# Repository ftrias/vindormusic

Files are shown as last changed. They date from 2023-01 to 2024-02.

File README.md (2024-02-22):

Vindor ES Source Code
=====================

This repository holds the source code, modules and PCB layouts of the Vindor ES1/2 electronic saxophone and wind instrument (clarinet, flute, trumpet, etc.). More information is available at [Vindor Music](http://vindormusic.com)

Directories
-----------

| Directory | Contents
| --- | ---
| /apps | Mobile and web apps
| /apps/juce-gui | Main control app for Mac/Win/iOS/Android
| /apps/splayer | Free generic MIDI player
| /firmware | Source for firmware and related modules
| /firmware/source | ES1/2 main source
| /firmware/external  | Non-Vindor open source libraries used
| /pcb | KiCad source for PCB
| /shell | Solidworks models for the shell
| /documents | Documentation and promotional material
| /sounds | Sound files for use on SD cards

License
-------

Unless otherwise noted, the software is Copyright (c) 2023 by Fernando Trias and Vindor Music, Inc. The software is licensed for use under the Creative Commons license available in `LICENSE.txt` and summarized on the [CC page](https://creativecommons.org/licenses/by-nc/3.0/).

This software uses external modules that are distributed according to their own licenses, which are all open source.

To summarize:
1. You may freely use this software for non-commercial purposes.
2. You must give appropriate credit to respective authors.

History
---------
This project began in 2016 to produce an affordable electronic wind instrument. At that time, the market was dominated by Yamaha and Akai. Both produced superb instruments that were prohibitively expensive for casual musicians. In addition, there were a number of small niche manufacturers targeting advanced players. Although Akai produced a low-cost USB instrument, it was large, heavy and had limited market penetration. In addition, we wanted to create an easy-to-use low-cost alternative for beginning players that would be both stand-alone and interface easily with Garageband and similar apps popular with younger musicians.

The Vindor began with a Kickstarter campaign and started being sold commercially in 2018 both online and in stores. It was covered by numerous blogs and journals, including Fast Company and the Boston Globe. In 2019, Roland release the Aerophone Mini AE-01, which although larger and slightly more expensive than the Vindor, targeted the same entry-level market. This, combined with the COVID shutdown and subsequent rise in component costs, made producing more Vindors impractical and all existing inventory was sold out by late 2020. 

By 2023, the chip market had not recovered and it still not possible to make more Vindors (the main CPU is still unavailable). Since Vindor Music closed its doors, we have decided to open source the firmware and apps, as well as the PCB, BOM and other components.

Open Source Announcement
------------------------

Vindor Music has open sourced the ES1 electronic wind instrument software and hardware. The Vindor ES1 was a low-cost entry-level electronic wind instrument that launched in 2018 and sold until 2020, a casualty of the COVID pandemic. The release includes all the source for the firmware, Android, iOS, Mac and Windows apps, as well as the BOM, schematics and PCB layout of the circuit boards. It includes everything you need to make your own ES1 and program it to do whatever you like. We hope this will inspire hobbyists to port the ES1 to a new CPU and continue the mission of providing an affordable and functional electronic wind instrument. The source can be found at https://github.com/ftrias/vindormusic.

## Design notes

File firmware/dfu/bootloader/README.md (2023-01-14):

Fadecandy Bootloader
====================

This is a simple open source bootloader for the Freescale Kinetis MK20DX128 microcontroller. It uses the USB Device Firmware Upgrade (DFU) standard. This bootloader was developed for use with Fadecandy, but it should be portable with to other projects using chips in the Kinetis microcontroller family.

Installing
----------

On a Teensy 3.0, you can use the Teensy Loader application to install `fc-boot.hex`. Afterwards, your Teensy should appear to the system as a "Fadecandy Bootloader" USB device capable of loading an application firmware image.

On a Fadecandy fc64x8 board, the bootloader can be installed via JTAG using OpenOCD. If you have an Olimex ARM-USB-OCD adapter, everything's already set up to install the bootloader with "make install". Other JTAG adapters will require changing `openocd.cfg`.

Application Interface
---------------------

This section describes the programming interface that exists between the bootloader and the application firmware.

The bootloader uses the smallest possible protected region on the MK20DX128's flash, a 4KB block. It uses a tiny amount of RAM for a "token" which is used to force entry into the bootloader on system reset.

When entering the application firmware, the system clocks will already be configured, and the watchdog timer is already enabled with a 10ms timeout. The application may disable the watchdog timer if desired.

The bootloader normally transfers control to the application early in boot, before setting up the USB controller. It will skip this step and run the DFU implementation if any of the following conditions are true:

* A banner ("FC-Boot\n") printed to the hardware UART at 9600 baud is echoed back within one character-period. (Manual entry by shorting TX and RX)
* A 32-bit entry token (0x74624346, or 'FCbt') is found at 0x2000_1FFC. (Programmatic entry)
* The application ResetVector does not reside within application flash. (No application is installed)

Memory address range       | Description
-------------------------- | ----------------------------
0x0000_0000 - 0x0000_0FFF  | Bootloader protected flash
0x0000_1000 - 0x0000_10F7  | Application IVT in flash
0x0000_1000 - 0x0001_FFFF  | Remainder of application flash
0x1FFF_E000 - 0x2000_1FFC  | Application SRAM
0x2000_1FFC - 0x2000_1FFF  | Entry token in SRAM

External Hardware
-----------------

No external hardware is required for the bootloader to operate. The following pins are used by the bootloader for optional features:

* PC5 is a status LED, active (high) while the bootloader is in DFU mode.
* PCR16/17 are set up as UART0 briefly during boot, for broadcasting the banner message and testing for manual bootloader entry.

File Format
-----------

The DFU file consists of raw 1 kilobyte blocks to be programmed into flash starting at address 0x0000_1000. The file may contain up to 127 blocks. No additional headers or checksums are included. On disk, the standard DFU suffix and CRC are used. During transit, the standard USB CRC is used.

Contact
-------

Micah Elizabeth Scott <<micah@scanlime.org>>

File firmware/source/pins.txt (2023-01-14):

 Notes on pin connections: R45

 Pin = K20 pin designation
 ##  = Teensy emulation pin number
 Purpose = Notes on use

 Pin   ## Purpose
 ----- -- -------------
 PTA0     SWD Clock
 PTA1  34X T9 CH2
 R44< PTA2  #? SET
 R45> PTA2  35X Tb CH3
 PTA2  #? SET
 PTA3     SWD DIO
 PTA4  33 T6 CH5
 R44< PTA5  24 SD card det
 R45> PTA5  24 SET
 PTA12  3 SG I2S DIN (I2S0_TXD0)
 PTA13  4 SG I2S LRCLK
 PTA18  X Clock
 PTA19  X Clock
 PTB0  16 T4 CH0
 PTB1  17 T5 CH6
 PTB2  19 T8 CH7
 PTB3  18 T7 CH8
 PTB16  0 T1 CH9
 PTB17  1 T2 CH10
 PTB18 32 T3 CH11
 PTB19 25 T11 CH12
 PTC0  15 T10 CH13
 PTC1  22 T_HI CH14
 PTC2  23 T_LO CH15
 PTC3   9 SG I2S_SCLK
 PTC4  10 SD CD/DAT3
 PTC5  13 SD CLK (SCK)
 PTC6  11 SD CMD (DOUT MOSI)
 PTC7  12 SD DAT0 (DIN MISO)
 PTC8  28 SG MCLK
 PTC9  27 LDO EN
 PTC10 29 SG CTRL_CLK
 PTC11 30 SG CTRL_DATA
 PTD0   2 AMP SHDN
 X18  A14 Air Pressure (K20 pin ADC_SE23)
 PTD2   7 Serial3 RX
 PTD3   8 Serial3 TX
 PTD4   6 LED Red
 PTD5  20 SG I2S DOUT? - should connect to I2S0_RXD0
 PTD6  21 LED Green
 PTD7   5 LED Blue
 PTE0  31 HP Jack Det
 PTE1  26 Line Jack Det
 PTE4  38 Accelerometer CS
 PTE5  39 Accelerometer control button

 Free pin #14 PTD1
 Possible changes to free more digital pins: move HP/Line jack detect to ADC_DP* and remove interrupt on those lines

 Revision R53 w/ 64-pin chip
 PTE0      31 Accel CS
 PTE1      26 Accel button
 ADC0_DM0 A11 Battery volt
 ADC0_DP0 A10 HP_JACK HP Jack Det
 PTD1      14 Line Jack Det

 Why is VREF_OUT connected to ground via capacitor? High pass filter?

Notes on pin connections: R57

 Pin = K20 pin designation
 ##  = Teensy emulation pin number
 Purpose = Notes on use

 Pin   ##   Purpose
 ----- --   -------------
 PTA0       SWDCLK SWD Clock
 PTA1  34X  T8 CH2
 PTA2  35X  Tb CH3
 PTA3       SWDIO SWD DIO
 PTA4  33   T5 CH5
 PTA5  24   SET button
 PTA12  3   SGTL5000 I2S DIN (I2S0_TXD0)
 PTA13  4   SGTL5000 I2S LRCLK
 PTA18  X   Clock
 PTA19  X   Clock
 PTB0  16   T3 CH0
 PTB1  17   T4 CH6
 PTB2  19   T7 CH7
 PTB3  18   T6 CH8
 PTB16  0   T11 CH9
 PTB17  1   T1 CH10
 PTB18 32   T2 CH11
 PTB19 25   T10 CH12
 PTC0  15   T9 CH13
 PTC1  22   T_HI CH14
 PTC2  23   T_LO CH15
 PTC3   9   SGTL5000 I2S_SCLK
 PTC4  10   SD CD/DAT3
 PTC5  13   SD CLK (SCK) / Accl SCL
 PTC6  11   SD CMD (DOUT MOSI) / Accel SDA
 PTC7  12   SD DAT0 (DIN MISO) / Accel SDO
 PTC8  28   SGTL5000 MCLK
 PTC9  27   AUDIO SPEAKER LDO EN
 PTC10 29   SGTL5000 CTRL_CLK / Var Pot SCL / Display
 PTC11 30   SGTL5000 CTRL_DATA / Var Pot SDA / Display
 PTD0   2   AMP SPEAKER SHDN
 X18  A14   Air Pressure (K20 pin ADC_SE23)
 PTD1  14   Amplifier Lineout Jack
 PTD2   7   Serial3 RX / JESP01:RX
 PTD3   8   Serial3 TX / JESP01/TX
 PTD4   6   LED Red
 PTD5  20   SGTL5000 I2S DOUT
 PTD6  21   LED Green
 PTD7   5   LED Blue
 PTE0  31   Accelerometer CS
 PTE1  26   Thumb switch
 ADC0_DM0 A11 Battery volt reading
 ADC0_DP0 A10 HP_JACK HP Jack Det
 ADC0_DM3     -Free
 ADC0_DP3     -Free

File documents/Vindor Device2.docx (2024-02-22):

# Vindor Assembly

# Overview

# Bottom

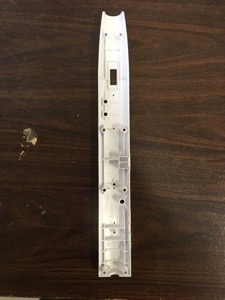
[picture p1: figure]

Place thick grounding wires into holes from the bottom. Long side of the wire goes toward the front.

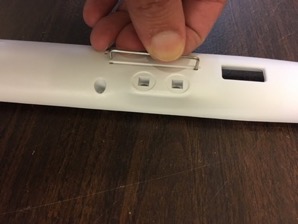
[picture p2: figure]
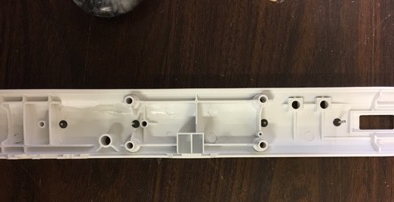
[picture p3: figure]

Find the small “Octave” PCB and attach LCD/OLED display.

Insert into bottom shell making sure that LCD fills hole completely.

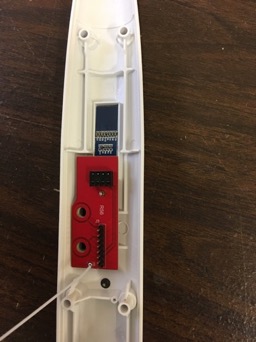
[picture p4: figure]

Attach cylinder on white wire to the thick grounding wire near the thumb hook.

Place the thumb hook and screw in with ½” screw.

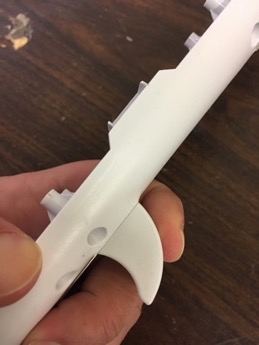
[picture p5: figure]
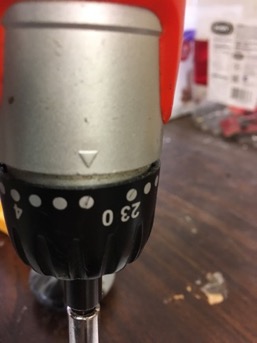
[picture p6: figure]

Attach tubes to the mouthpiece holder. Middle tube is smaller than outer tube. Then attach other end of the bigger tube to the hole near the far side of the bottom shell.

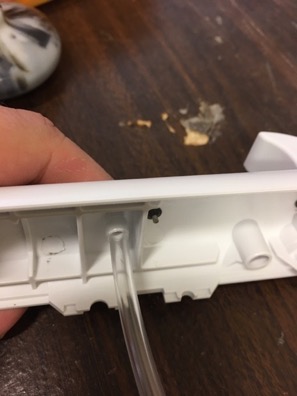
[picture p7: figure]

Place two carriage bolts. Then screw nuts from the opposite side using torque 4. Use locktite.

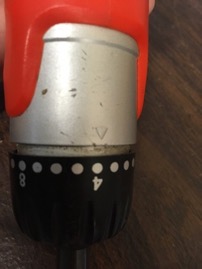
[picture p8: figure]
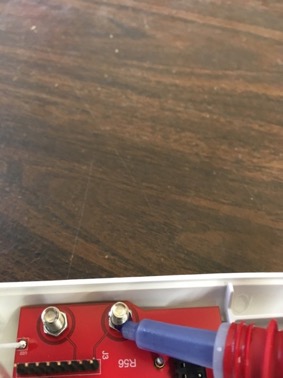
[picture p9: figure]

Use hot glue to permanently attach LCD/OLED to the shell. This prevents users from pushing the LCD into the shell.

# PCB prep

Place battery into PCB with plus side forward (see silkscreen on PCB) and ensure power switch is on by flipping it in the direction of the battery.

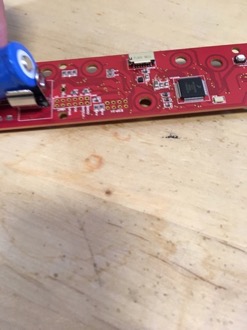
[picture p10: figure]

Flash the firmware. I use Segger J-Link.

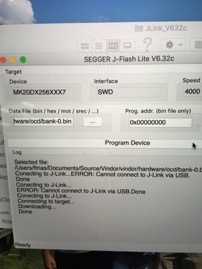
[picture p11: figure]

On the bottom side of the PCB, insert the button cap.

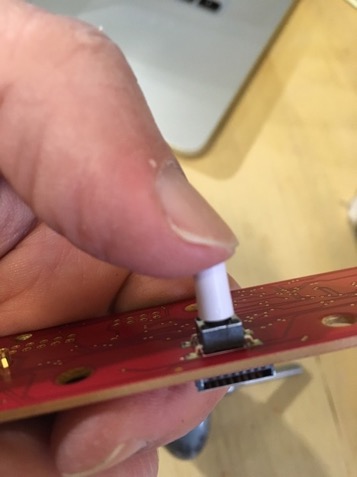
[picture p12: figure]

Near the battery, insert the light pipe. Then place the switch cap on the power switch.

# Top

Place the speaker foam near the top. Make sure it is oriented correctly. Place the speaker and screw in ¼” screws (4 of them) using torque 0.

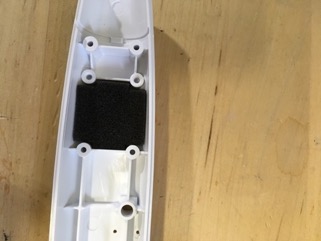
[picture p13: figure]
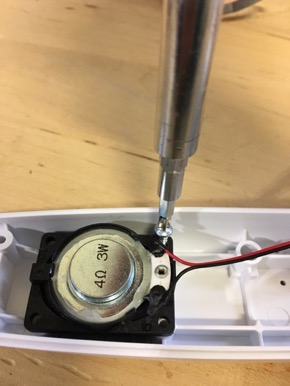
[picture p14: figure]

Optional. Place plastic washer on 4th hole and put in carriage screw.

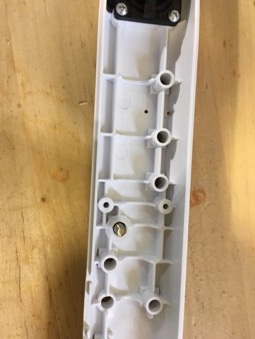
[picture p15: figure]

Attach bent wire into holes between first two bolt holes. Longer side goes on the inside, and shorter side on the outside. Use pressing tool to attach compression nut to the longer side of shell.

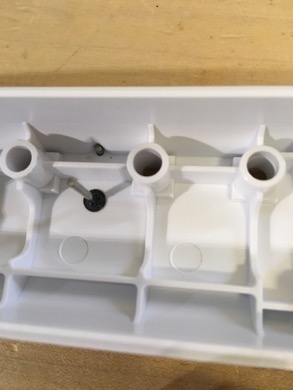
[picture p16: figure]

# Put it all together

Place the PCB into the top shell making sure the bent wire goes into the cylinder compression piece.

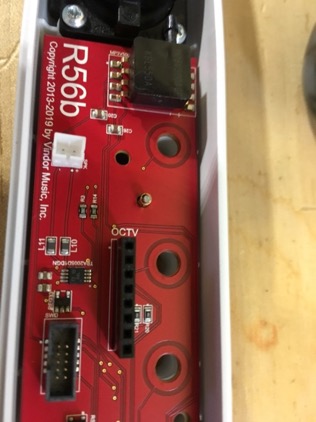
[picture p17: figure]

Optional. Screw in any bolts you optionally placed for support.

Carefully flip the top shell over and place all the carriage bolts into the proper holes.

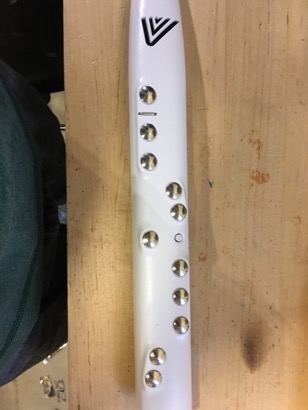
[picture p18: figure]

Place a piece of cardboard or other hard part on top of the shell and flip it over. The cardboard prevents the bolts from falling off.

Using a placement tool, put on all the nuts on the bolts.

Using torque 4, screw down the nuts.

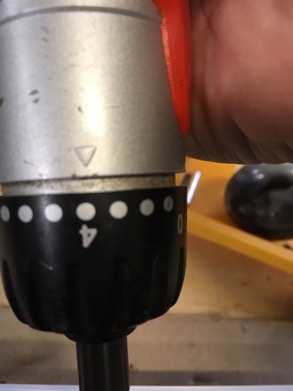
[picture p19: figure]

Use loctite on nuts.

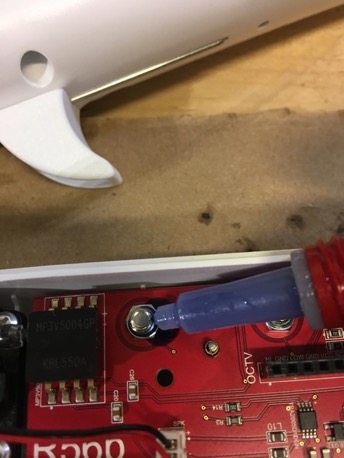
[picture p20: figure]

Attach the speaker wire.

Attach the small tube the air pressure sensor.

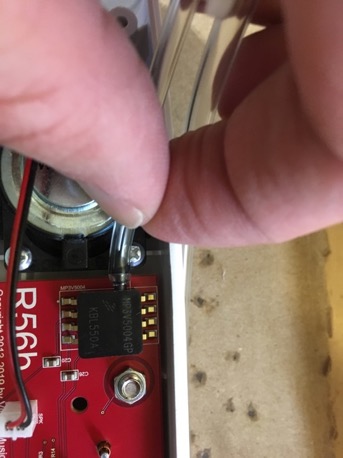
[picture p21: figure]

Place the mouthpiece holder in its place making sure to line up guide groove.

The top and bottom are ready for assembly.

Carefully guide tube between button and battery by pushing it into place.

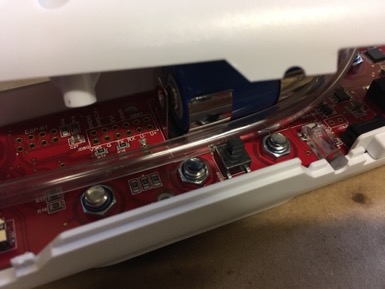
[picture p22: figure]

Place the long cap on the button.

Join the top and bottom. Make sure the cap you just placed goes through the hole. Also make sure that the header pins on the front of the “Octave” PCB line up with the mating header on the main PCB.

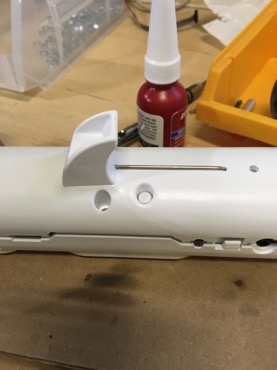
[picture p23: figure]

Using torque 1, screw in ¾” screws (6 of them) on the bottom shell.

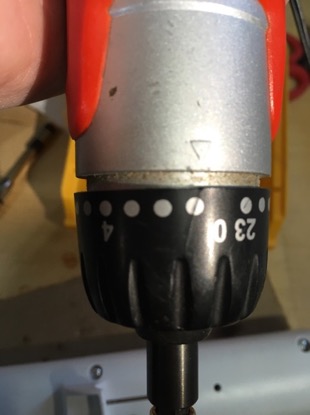
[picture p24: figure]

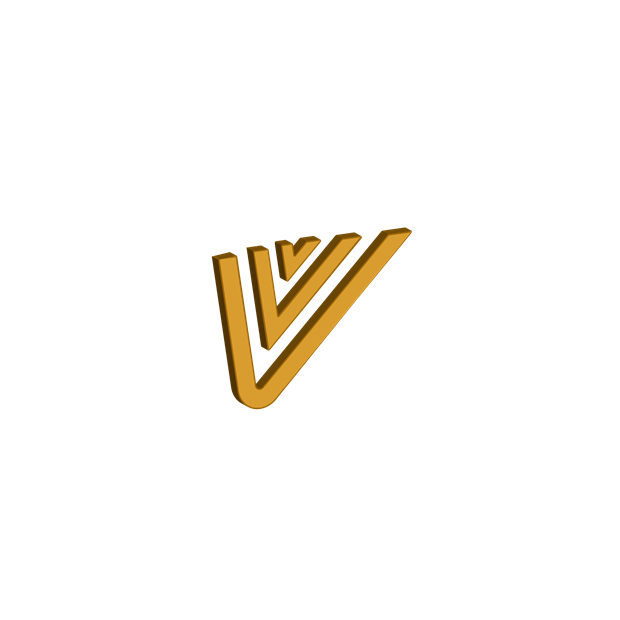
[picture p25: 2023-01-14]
apps/splayer/splayer/Dist/Vindor WAP/Vindor WAP/Assets/LargeTile.scale-200.png

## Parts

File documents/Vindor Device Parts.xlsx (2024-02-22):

 | Qty per Piece | Who provides | Origin
Shell
Shell top | 1 | Vindor | Molder
Shell bottom | 1 | Vindor | Molder
Mouthpiece holder | 1 | Vindor | Molder
Thumb hook | 1 | Vindor | Molder
Thumb button cap | 1 | Vindor | Molder
Power switch cap | 1 | Vindor | Molder
Bent wire
Long wire | 2 | Vindor | Custom
Short wire | 1 | Vindor | Custom
Push nuts | 5 | Mfg |  | https://www.mcmaster.com/catalog/94807A015
Octave board
Octave PCB | 1 | Mfg | PCB
LCD/OLED | 1 | Mfg | Alibaba
Screws/bolts
Thread-forming 1/4" #4-20 | 4 | Mfg |  | https://www.mcmaster.com/catalog/90380A106
Thread-forming 1/2" #4-20 | 1 | Mfg |  | https://www.mcmaster.com/catalog/90380A110
Thread-forming 3/4" #4-20 | 6 | Mfg |  | https://www.mcmaster.com/catalog/90380A120
Carriage bolts 3/4" 10-20 | 13 | Mfg |  | https://www.mcmaster.com/catalog/92356A245
1/4" 10-24 narrow nuts | 13 | Mfg |  | https://www.mcmaster.com/catalog/90760A120
Main board
PCB | 1 | Mfg | PCB
Light pipe | 1 | Mfg |  | https://www.digikey.com/product-detail/en/7513D2-S/7513D2-S-ND/415950
Top button cap | 1 | Mfg |  | https://www.digikey.com/product-detail/en/e-switch/1RWHT/EG1881-ND/271578
Battery 16340 | 1 | Mfg | Alibaba
Misc
Speaker with wire | 1 | Vindor | Modified | https://www.digikey.com/product-detail/en/pui-audio-inc/AS04004PO-2-R/668-1234-ND/1745528
Foam for speaker | 1 | Vindor | Custom
Small tube 3/32" (qty inches) | 3 | Mfg |  | https://www.mcmaster.com/catalog/5231K948
Large tube 1/8" (qty inches) | 11 | Mfg |  | https://www.mcmaster.com/catalog/5231K315
Extras
Clarinet mouthpiece | 1 | Vindor | Alibaba
Ligature | 1 | Vindor | Alibaba
Cap | 1 | Vindor | Alibaba
Plastic reed | 1 | Vindor | Bravo | Shun Hwa Chang <pobox3387@gmail.com>
USB micro cable | 1 | Mfg | Alibaba
USB charger | 1 | Mfg | Alibaba
Quick-start guide | 1 | Vindor | Vistaprint
Box | 1 | Vindor | Romanow | http://www.romanowcontainer.com/
Tools
Torque screwdriver
1/4" nut driver
Phillips driver (#1)
Hot glue
Nut placement tool
Push nut installation tool
Loctite

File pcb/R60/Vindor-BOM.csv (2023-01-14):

Reference | Value | Footprint | Manufacturer | MPN
BTNEG1 | KEYSTONE 54 | Vindor:KEYSTONE_54 |  | Keystone 54
BTPOS1 | KEYSTONE 54 | Vindor:KEYSTONE_54 |  | Keystone 54
C1 | 10 uf | MF_Passives:MF_Passives-C1206 |  | MF-CAP-1206-10uF
C10 | 0.1 uf | MF_Passives:MF_Passives-C0603 |  | MF-CAP-0603-0.1uF
C11 | 0.1 uf | MF_Passives:MF_Passives-C0603 |  | MF-CAP-0603-0.1uF
C12 | 0.1 uf | MF_Passives:MF_Passives-C0603 |  | MF-CAP-0603-0.1uF
C13 | 0.1 uf | MF_Passives:MF_Passives-C0603 |  | MF-CAP-0603-0.1uF
C14 | 0.1 uf | MF_Passives:MF_Passives-C0603 |  | MF-CAP-0603-0.1uF
C15 | 0.1 uf | MF_Passives:MF_Passives-C0603 |  | MF-CAP-0603-0.1uF
C16 | 0.1 uf | MF_Passives:MF_Passives-C0603 |  | MF-CAP-0603-0.1uF
C17 | 0.1 uf | MF_Passives:MF_Passives-C0603 |  | MF-CAP-0603-0.1uF
C18 | 0.1 uf | MF_Passives:MF_Passives-C0603 |  | MF-CAP-0603-0.1uF
C19 | 10 uf | MF_Passives:MF_Passives-C1206 |  | MF-CAP-1206-10uF
C2 | 1 uf | MF_Passives:MF_Passives-C0603 |  | MF-CAP-0603-1uF
C20 | 1 uf | MF_Passives:MF_Passives-C0603 |  | MF-CAP-0603-1uF
C21 | 1 uf | MF_Passives:MF_Passives-C0603 |  | MF-CAP-0603-1uF
C3 | 0.1 uf | MF_Passives:MF_Passives-C0603 |  | MF-CAP-0603-0.1uF
C4 | 0.1 uf | MF_Passives:MF_Passives-C0603 |  | MF-CAP-0603-0.1uF
C5 | 4.7 uf | MF_Passives:MF_Passives-C0603 |  | CL10A475KQ8NNNC
C6 | 4.7 uf | MF_Passives:MF_Passives-C0603 |  | CL10A475KQ8NNNC
C7 | 0.1 uf | MF_Passives:MF_Passives-C0603 |  | MF-CAP-0603-0.1uF
C8 | 0.1 uf | MF_Passives:MF_Passives-C0603 |  | MF-CAP-0603-0.1uF
C9 | 0.1 uf | MF_Passives:MF_Passives-C0603 |  | MF-CAP-0603-0.1uF
CA1 | 100 nf | MF_Passives:MF_Passives-C1210 |  | ECHU1C104JX5
CA2 | 100 nf | MF_Passives:MF_Passives-C1210 |  | ECHU1C104JX5
D1 | MF-DIO-SMA-B140 | MF_Discrete_Semiconductor:MF_Discrete_Semiconductor-SMA |  | MF-DIO-SMA-B140
D2 | MF-LED-0603-RED | MF_LEDs:MF_LEDs-LED0603 |  | MF-LED-0603-RED
D3 | LED_RGB_CA_PLCC4 | MF_LEDs:MF_LEDs-PLCC4 |  | MF-LED-ASMB-RGB
FB1 | BLM21AG601SN1D | Inductor_SMD:L_0805_2012Metric |  | 742792040
FB2 | BLM21AG601SN1D | Inductor_SMD:L_0805_2012Metric |  | 742792040
FB3 | BLM21AG601SN1D | MF_Passives:MF_Passives-C0805 |  | BLM21AG601SN1D
FB4 | BLM21AG601SN1D | MF_Passives:MF_Passives-C0805 |  | BLM21AG601SN1D
FB5 | BLM21AG601SN1D | MF_Passives:MF_Passives-C0805 |  | BLM21AG601SN1D
J1 | 10137062-00021LF | Vindor:USBC_10137062-00021LF |  | 10137062-00021LF
J2 | 35RASMT4BHNTRX | 35RASMT4BHNTRX:SWITCHCRAFT_35RASMT4BHNTRX |  | 35RASMT4BHNTRX
J3 | B2B-PH-SM4-TB(LF)(SN) | digikey-footprints:PinHeader_1x2_P2mm |  | B2B-PH-SM4-TB(LF)(SN)
J4 | 47309-3351 | Vindor:MOLEX_MICROSD_473093351 |  | 47309-3351
J5 | 2.54mm 01x08 Female | MF_Connectors:MF_Connectors-PTH_2.54MM_01X08 |  | PPTC081LFBN-RC
J8 | Conn_01x02_Male | MF_Connectors:MF_Connectors-PTH_2.54MM_01X02
JX1 | S9111-45R | Vindor:HARWIN_S9111_45R |  | S9111-45R
JX2 | S9111-45R | Vindor:HARWIN_S9111_45R-TIGHT |  | S9111-45R
R1 | 27 ohm | MF_Passives:MF_Passives-R0603 |  | MF-RES-0603-27
R10 | 47 ohm | MF_Passives:MF_Passives-R0603 |  | MF-RES-0603-47
R11 | 220 ohm | MF_Passives:MF_Passives-R0603 |  | MF-RES-0603-220
R12 | 470 ohm | MF_Passives:MF_Passives-R0603 |  | MF-RES-0603-470
R13 | 100 ohm | MF_Passives:MF_Passives-R0603 |  | MF-RES-0603-100
R14 | 100 ohm | MF_Passives:MF_Passives-R0603 |  | MF-RES-0603-100
R15 | 100 ohm | MF_Passives:MF_Passives-R0603 |  | MF-RES-0603-100
R16 | 10k ohm | MF_Passives:MF_Passives-L0603 |  | MF-RES-0603-10K
R17 | 10k ohm | MF_Passives:MF_Passives-L0603 |  | MF-RES-0603-10K
R18 | 5.1k ohm | MF_Passives:MF_Passives-R0603 |  | RC0603JR-075K1L
R19 | 5.1k ohm | MF_Passives:MF_Passives-R0603 |  | RC0603JR-075K1L
R2 | 27 ohm | MF_Passives:MF_Passives-R0603 |  | MF-RES-0603-27
R3 | 470 ohm | MF_Passives:MF_Passives-R0603 |  | MF-RES-0603-470
R4 | 470 ohm | MF_Passives:MF_Passives-L0603 |  | MF-RES-0603-470
R5 | 10k ohm | MF_Passives:MF_Passives-R0603 |  | MF-RES-0603-10K
R6 | 470 ohm | MF_Passives:MF_Passives-R0603 |  | MF-RES-0603-470
R7 | 18k ohm | MF_Passives:MF_Passives-R0603 |  | MF-RES-0603-18K
R8 | 18k ohm | MF_Passives:MF_Passives-R0603 |  | MF-RES-0603-18K
R9 | 47 ohm | MF_Passives:MF_Passives-R0603 |  | MF-RES-0603-47
RA1 | 20k ohm | MF_Passives:MF_Passives-R0603 |  | ERA-3AEB203V
RA2 | 20k ohm | MF_Passives:MF_Passives-R0603 |  | ERA-3AEB203V
S1 | TL3301EF100QG | TL3301EF100QG:SOIC450P1000X730-4N |  | TL3301SPF160QG
S2 | TL3301EF100QG | TL3301EF100QG:SOIC450P1000X730-4N |  | TL3301SPF160QG
S3 | 1825282-1 | Vindor:TE1825282-1 |  | 1825282-1
SW1 | MF-SW-TACT-4.2MM | PTS810_SJM_250_SMTR_LFS:SW_PTS810_SJM_250_SMTR_LFS |  | MF-SW-TACT-4.2MM
U1 | MK20DX256VLH7 | MK20DX256VLH7:MK20DX256VLH7 |  | MK20DX256VLH7
U10 | LSM6DS3TR | Vindor:LGA-14_3x2.5mm_P0.5mm |  | LSM6DS3TR
U11 | MP3V5004GP | Vindor:MP3V5004GP |  | MP3V5004GP
U2 | TLV70233_SOT23-5 | Package_TO_SOT_SMD:SOT-23-5 |  | MF-REG-SOT235-3.3V-300mA
U3 | MCP73831T-2ACI/OT | digikey-footprints:SOT-753 |  | MCP73831T-2ACI_OT
U4 | TLV70233_SOT23-5 | Package_TO_SOT_SMD:SOT-23-5 |  | MF-REG-SOT235-3.3V-300mA
U5 | MCP1703A | Package_TO_SOT_SMD:SOT-23 |  | MCP1703AT-1802E/CB
U6 | SGTL5000XNAA3 | Vindor:SGTL5000 |  | SGTL5000XNAA3
U7 | TS3A5018PW | TS3A5018PW:SOP65P640X120-16N |  | TS3A5018PW
U8 | TPA2005D1DGNRQ1 | Vindor:Vindor-MSOP-8-1EP_W3mm |  | TPA2005D1DGNRQ1
U9 | NMJ4HHD2 or NMJ6HHD2 | Vindor:NMJ6HFD2-center |  | NMJ4HHD2
XTAL1 | ECS-160-9-42-CKM-TR | Vindor:ECS-160-9-42-CKM-TR |  | ECS-160-9-42-CKM-TR

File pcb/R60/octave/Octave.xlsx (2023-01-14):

Reference | Value | Footprint | MPN
J2 | Conn_01x04_Female | Vindor:Moldex-0448120004 | 44812-0004
J3 | Conn_01x08_Male | Connector_PinHeader_2.54mm:PinHeader_1x08_P2.54mm_Vertical | MF-CONN-2.54mm-01x08
J1 | HARWIN_S9111-45R | Vindor:HARWIN_S9111_45R | S9111-45
J4 | Conn_01x02_Male | Connector_JST:JST_PH_S2B-PH-K_1x02_P2.00mm_Horizontal | S2B-PH-K-S(LF)(SN)
C1 | 0.1uF | MF_Passives:MF_Passives-C0603 | MF-CAP-0603-0.1uF
R1 | 50k | MF_Passives:MF_Passives-R0603 | MF-RES-0603-50K

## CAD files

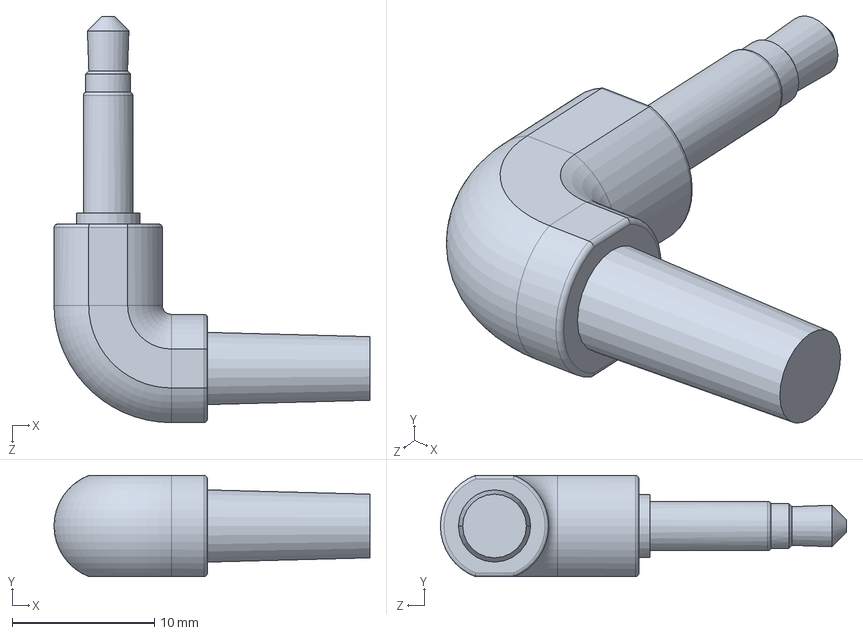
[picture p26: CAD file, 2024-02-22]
shell/solidworks/Vindor RevD/headphone jack.SLDPRT
22.2 x 7.11 x 28.6 mm

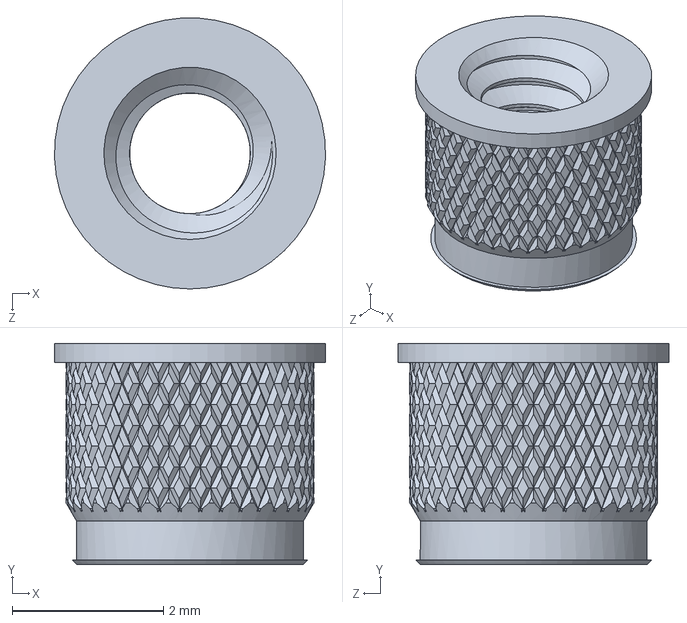
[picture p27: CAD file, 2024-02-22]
shell/solidworks/Vindor RevD/2-56 threaded insert 93365A110.SLDPRT
3.58 x 2.92 x 3.58 mm

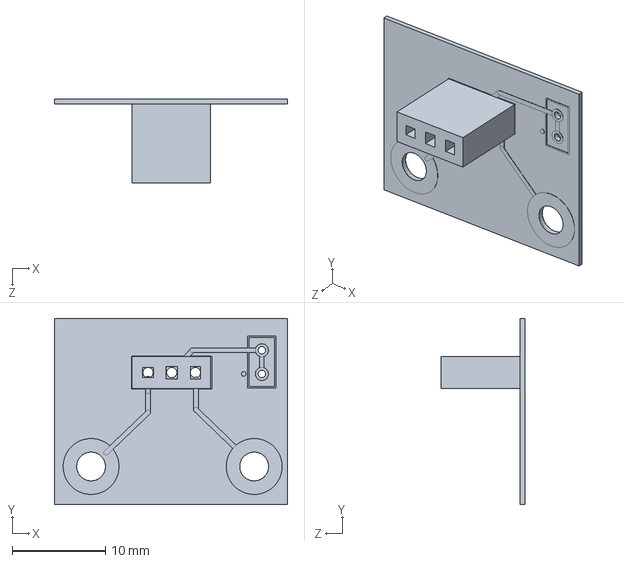
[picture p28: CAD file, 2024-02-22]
shell/solidworks/Vindor RevD/octave-board.SLDPRT
25.0 x 20.0 x 9.04 mm

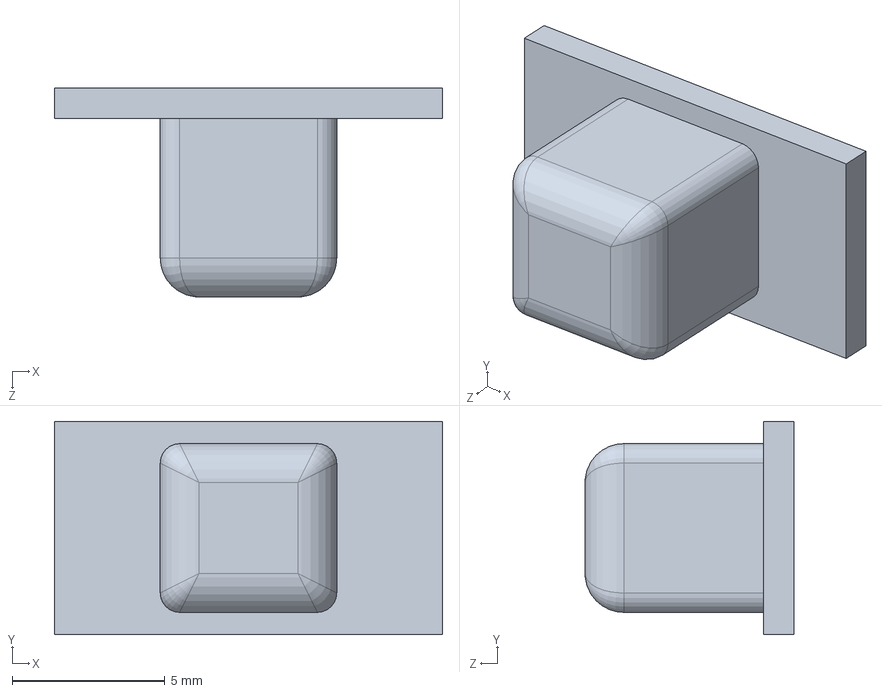
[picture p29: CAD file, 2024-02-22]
shell/solidworks/Vindor RevD/on off switch cap.SLDPRT
12.7 x 6.98 x 6.84 mm

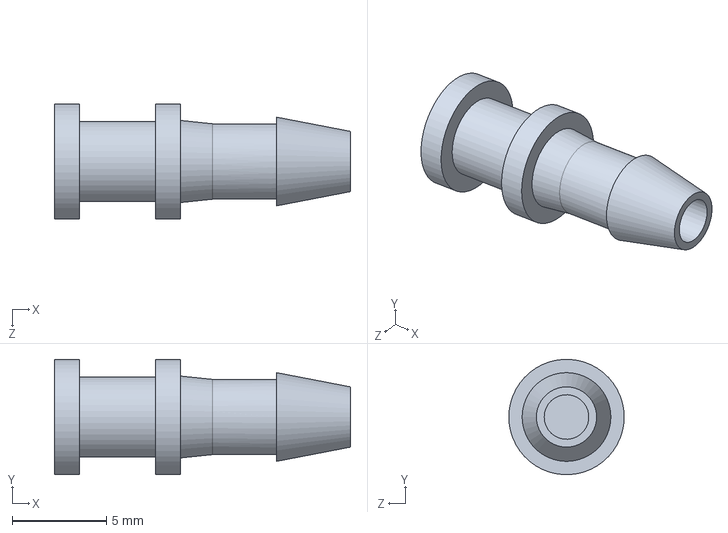
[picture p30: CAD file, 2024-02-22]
shell/solidworks/Vindor RevD/Tube Fitting 1_8in ID 2974K751.SLDPRT
15.7 x 6.10 x 6.11 mm

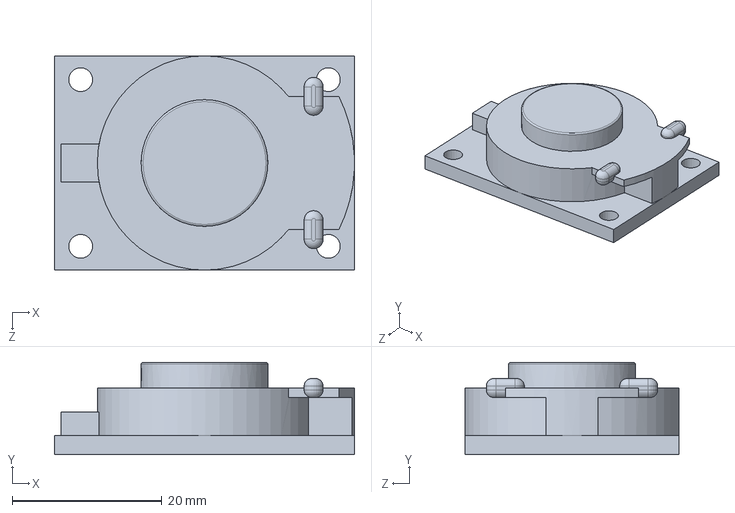
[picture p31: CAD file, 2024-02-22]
shell/solidworks/Vindor RevD/Speaker_revD.SLDPRT
40.0 x 12.3 x 28.6 mm

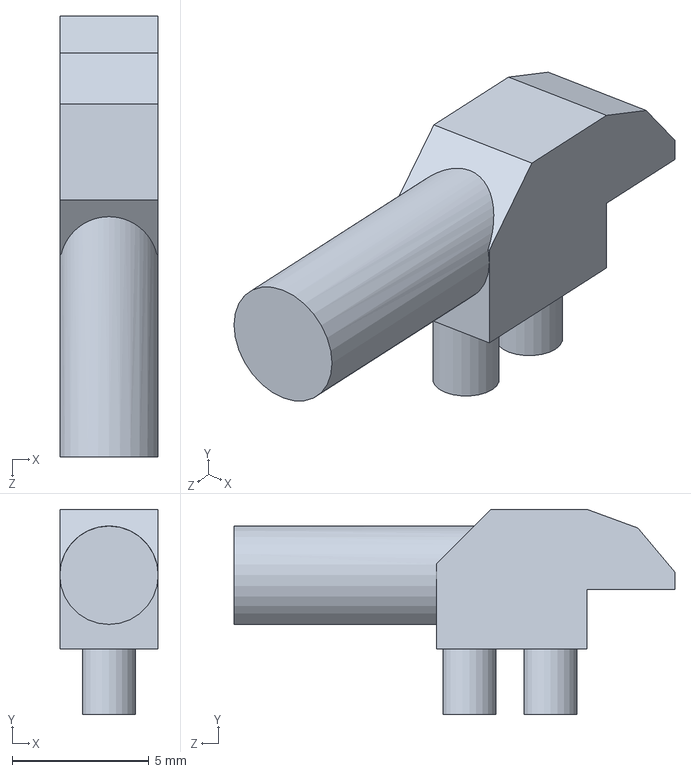
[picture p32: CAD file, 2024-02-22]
shell/solidworks/Vindor RevD/Light Pipe.SLDPRT
3.60 x 7.51 x 16.1 mm

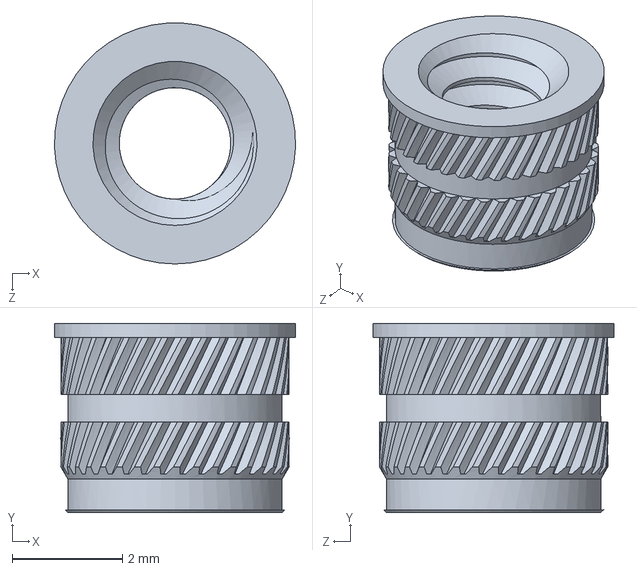
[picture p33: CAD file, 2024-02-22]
shell/solidworks/Vindor RevD/4-40 threaded insert 93365A120.SLDPRT
4.37 x 3.43 x 4.36 mm

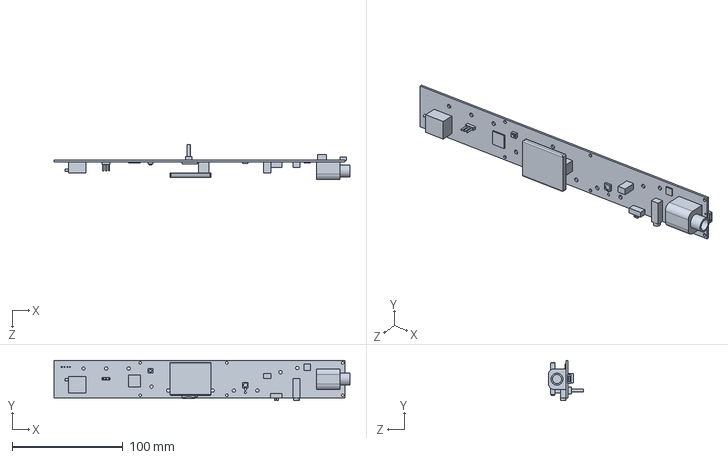
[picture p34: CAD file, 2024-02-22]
shell/solidworks/Vindor RevD/PCB-R43_revD.SLDPRT
267.3 x 36.5 x 31.6 mm

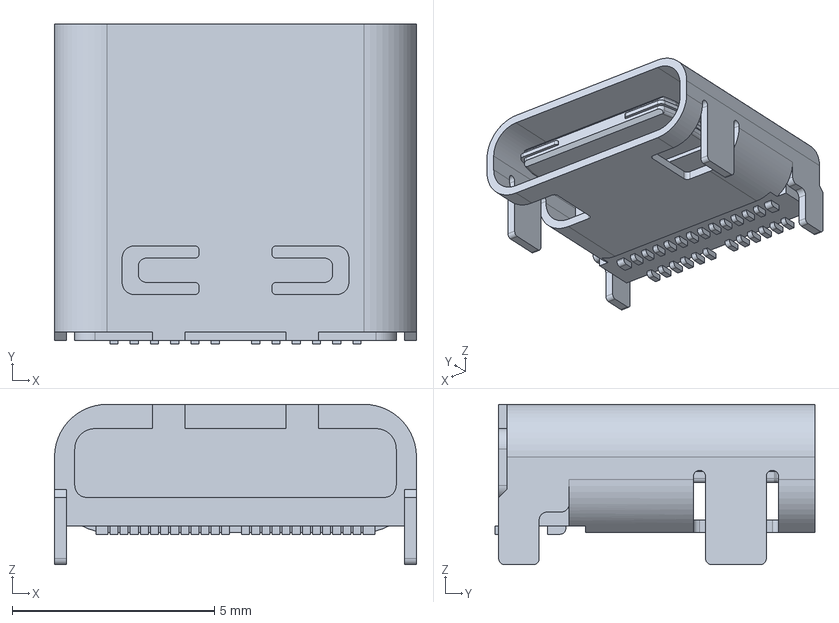
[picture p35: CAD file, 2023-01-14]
pcb/KiCad/105450-0101/1054500101.stp
8.94 x 7.90 x 3.96 mm

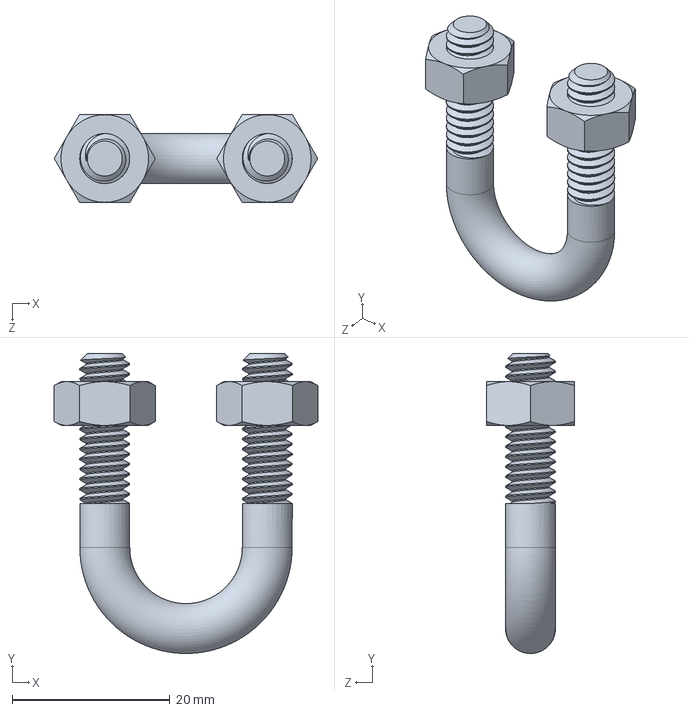
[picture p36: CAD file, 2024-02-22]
shell/solidworks/Vindor RevD/U-Bolt 8896T910.SLDPRT
33.5 x 38.1 x 11.1 mm

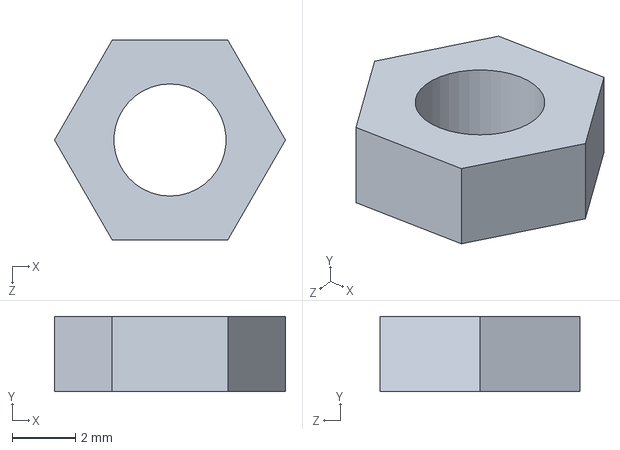
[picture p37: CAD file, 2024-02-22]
shell/solidworks/Vindor RevD/10-24 nut.SLDPRT
7.33 x 2.38 x 6.35 mm

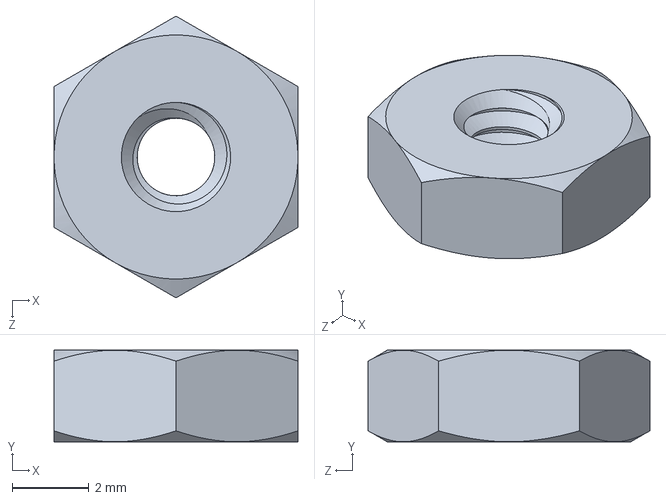
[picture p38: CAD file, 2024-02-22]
shell/solidworks/Vindor RevD/4-40 nut 91841A005.SLDPRT
6.35 x 2.38 x 7.33 mm

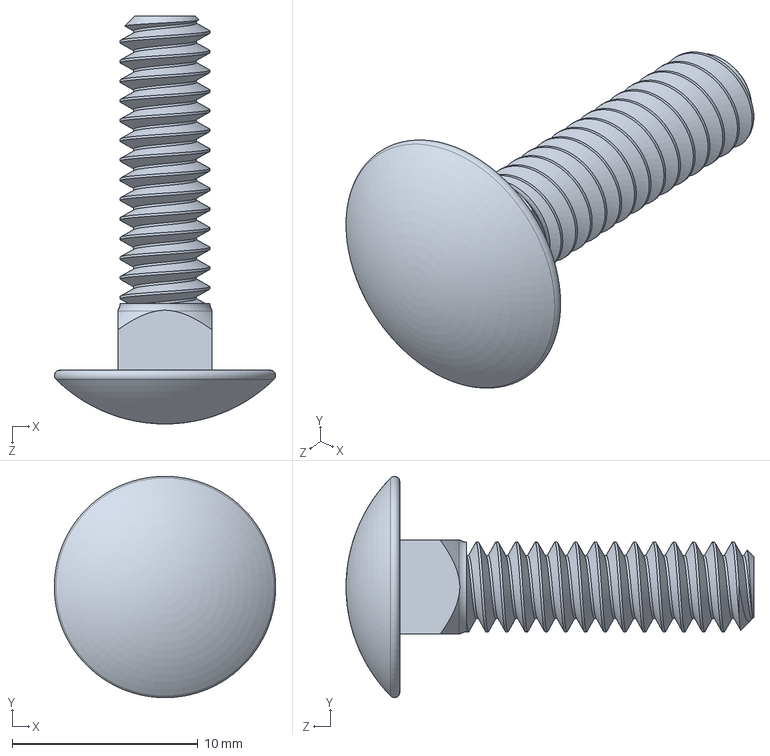
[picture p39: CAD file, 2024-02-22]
shell/solidworks/Vindor RevD/10-24 Carriage Bolt 3-4inlong 92356A245.SLDPRT
11.9 x 11.9 x 21.9 mm

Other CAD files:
shell/solidworks/Vindor RevD/2-56 screw 3_4in long 92196A084.SLDPRT
shell/solidworks/Vindor RevD/4-40 screw 7_16inlong 91772A109.SLDPRT
shell/solidworks/Vindor RevD/4-40 Thread lock screw 1_4inlong 93802A421.SLDPRT

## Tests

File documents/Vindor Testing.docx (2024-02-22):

# Vindor Testing

1. Turn on Vindor to run self-test. LED should turn blue briefly and then green.
2. Attach testing mouthpiece.
3. Blow to ensure speaker is making sound.
4. Touch lowest two metal pads and press the top button to change the mode to 4-octaves.
5. Attach headphones.
6. Blow and touch all metal pads in sequence to ensure that they all respond.
7. Disconnect headphones and attach amplifier.
8. Blow to make sure amplifier works.
9. Disconnect amplifier and attach USB.
10. Open up Vindor app and make sure it detects device.
11. Unplug USB.
12. Factory reset by touching first 3 pads and last 3 pads and pressing the top button.
13. Wait for green light and turn off.

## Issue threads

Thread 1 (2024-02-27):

help for diy noobs

Digilogue, 2024-02-27:
Hi, I was wondering if you could please create a download link so we can download the whole archive in a zip and or tar.gz?
Also, could you create a shared project link for the pcb and enclosure (pcbway?) . That way all that only has to be done one time and we can click a few buttons to order.
Thank you

ftrias, 2024-02-27:
If you go to the "Code" tab and click on the greed Code button you will see a link to download the project as a zip file. This includes the PCB files, which are in KiCad format. If you want enclosures, email me separately and I can ship you one.

Digilogue, 2024-02-27:
Hi! Thank you for responding.
Yes, I would appreciate the enclosure. Is there somewhere where I can make payment?
As per the pcb, I'm begging you, I don't know which files to load where. Can you please setup some kind of cart or shared project, then they've already analyzed cost and I can then just make purchase. Thank you so much for considering.

Sent with [Proton Mail](https://proton.me/) secure email.

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

ftrias, 2024-02-28:
The basic problem is that the main CPU is no longer being made. NXP, the
maker, promises to restart production, but they haven't in over two years
so basically there is no way to make any more Vindors. I put this project
up so someone else could port the code to a new CPU or in case it ever goes
back into production.

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

Digilogue, 2024-02-28:
Oh, that happened to Plinky too. They have new progress but I'm still not able to order the pcb yet. They had it set up before with pcbway. Perhaps pcbway can get the CPU now?
Which model of CPU is it?
I promise to contribute in my noob way.

Sent with [Proton Mail](https://proton.me/) secure email.

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

Digilogue, 2024-02-28:
Nevermind on the CPU question.
I'm sorry I was so pushy. It's very frustrating, and Im sure you feel the same. I was on plinkys second waiting list and lost my email, so the Plinky wait is over 2 years now. When that project wasn't starting, I started microdexed touch project and just got one running the other day, it took me that long, and teensy was the first thing I bought!
I'm making progress.

Sent with [Proton Mail](https://proton.me/) secure email.

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
>>> Hi! Thank you for responding.
>>> Yes, I would appreciate the enclosure. Is there somewhere where I can make
>>> payment?
>>> As per the pcb, I'm begging you, I don't know which files to load where.
>>> Can you please setup some kind of cart or shared project, then they've
>>> already analyzed cost and I can then just make purchase. Thank you so much
>>> for considering.
>>>
>>> Sent with [Proton Mail](https://proton.me/) secure email.
>>>
>>> On Tuesday, February 27th, 2024 at 4:04 AM, Fernando Trias ***@***.***>
>>> wrote:
>>>
>>> > If you go to the "Code" tab and click on the greed Code button you will
>>> see a link to download the project as a zip file. This includes the PCB
>>> files, which are in KiCad format. If you want enclosures, email me
>>> separately and I can ship you one.
>>> >
>>> > —
>>> > Reply to this email directly, [view it on GitHub](
>>> https://github.com/ftrias/vindormusic/issues/1#issuecomment-1966399261),
>>> or [unsubscribe](
>>> https://github.com/notifications/unsubscribe-auth/BGOF2SCBZ6P6LK7XUNSM373YVXDWJAVCNFSM6AAAAABD3NPOEKVHI2DSMVQWIX3LMV43OSLTON2WKQ3PNVWWK3TUHMYTSNRWGM4TSMRWGE
>>> ).
>>> > You are receiving this because you authored the thread.Message ID:
>>> ***@***.***>
>>>
>>> —
>>> Reply to this email directly, view it on GitHub
>>> <https://github.com/ftrias/vindormusic/issues/1#issuecomment-1967070392>,
>>> or unsubscribe
>>> <https://github.com/notifications/unsubscribe-auth/ABRWXIV55REGDCSB4UW2VP3YVYER5AVCNFSM6AAAAABD3NPOEKVHI2DSMVQWIX3LMV43OSLTON2WKQ3PNVWWK3TUHMYTSNRXGA3TAMZZGI>
>>> .
>>> You are receiving this because you commented.Message ID:
>>> ***@***.***>
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

Digilogue, 2024-03-01:
Hello again.
Did you mean the MK20DX256VLH7 ?
Digikey has over 2000 of those in stock right now.

Sent with [Proton Mail](https://proton.me/) secure email.

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
>>> The basic problem is that the main CPU is no longer being made. NXP, the
>>> maker, promises to restart production, but they haven't in over two years
>>> so basically there is no way to make any more Vindors. I put this project
>>> up so someone else could port the code to a new CPU or in case it ever goes
>>> back into production.
>>>
>>> On Tue, Feb 27, 2024 at 11:45 AM Digilogue ***@***.***> wrote:
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
>>> —
>>> Reply to this email directly, [view it on GitHub](https://github.com/ftrias/vindormusic/issues/1#issuecomment-1967959273), or [unsubscribe](https://github.com/notifications/unsubscribe-auth/BGOF2SFRPNJ3QFFBLESIFLLYVZ2IJAVCNFSM6AAAAABD3NPOEKVHI2DSMVQWIX3LMV43OSLTON2WKQ3PNVWWK3TUHMYTSNRXHE2TSMRXGM).
>>> You are receiving this because you authored the thread.Message ID: ***@***.***>

Digilogue, 2024-03-03:
Hi again.
I was just hoping to get an understanding of the current and near future of this project? I'm still hoping for a pcbway setup link so I can get started if they can get the chip.
Thank you

Sent with [Proton Mail](https://proton.me/) secure email.

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
>>> Oh, that happened to Plinky too. They have new progress but I'm still not able to order the pcb yet. They had it set up before with pcbway. Perhaps pcbway can get the CPU now?
>>> Which model of CPU is it?
>>> I promise to contribute in my noob way.
>>>
>>> Sent with [Proton Mail](https://proton.me/) secure email.
>>>
>>> On Tuesday, February 27th, 2024 at 4:23 PM, Fernando Trias ***@***.***> wrote:
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

ftrias, 2024-03-03:
I'm not quite sure yet. With the CPU in stock, I will have to see if I can set up something like the pcbway project. The only difficulty there will be programming the firmware to flash, which requires special hardware. Give me a few days to see what's possible.

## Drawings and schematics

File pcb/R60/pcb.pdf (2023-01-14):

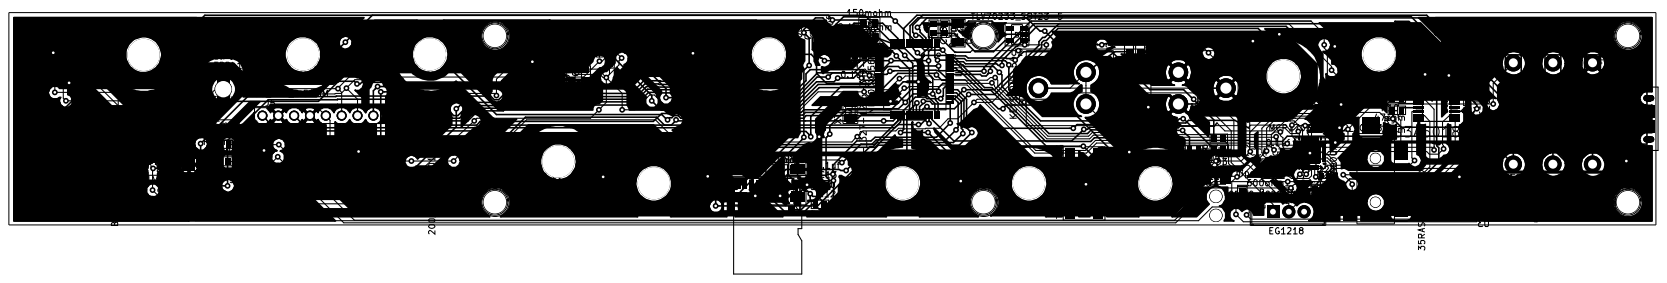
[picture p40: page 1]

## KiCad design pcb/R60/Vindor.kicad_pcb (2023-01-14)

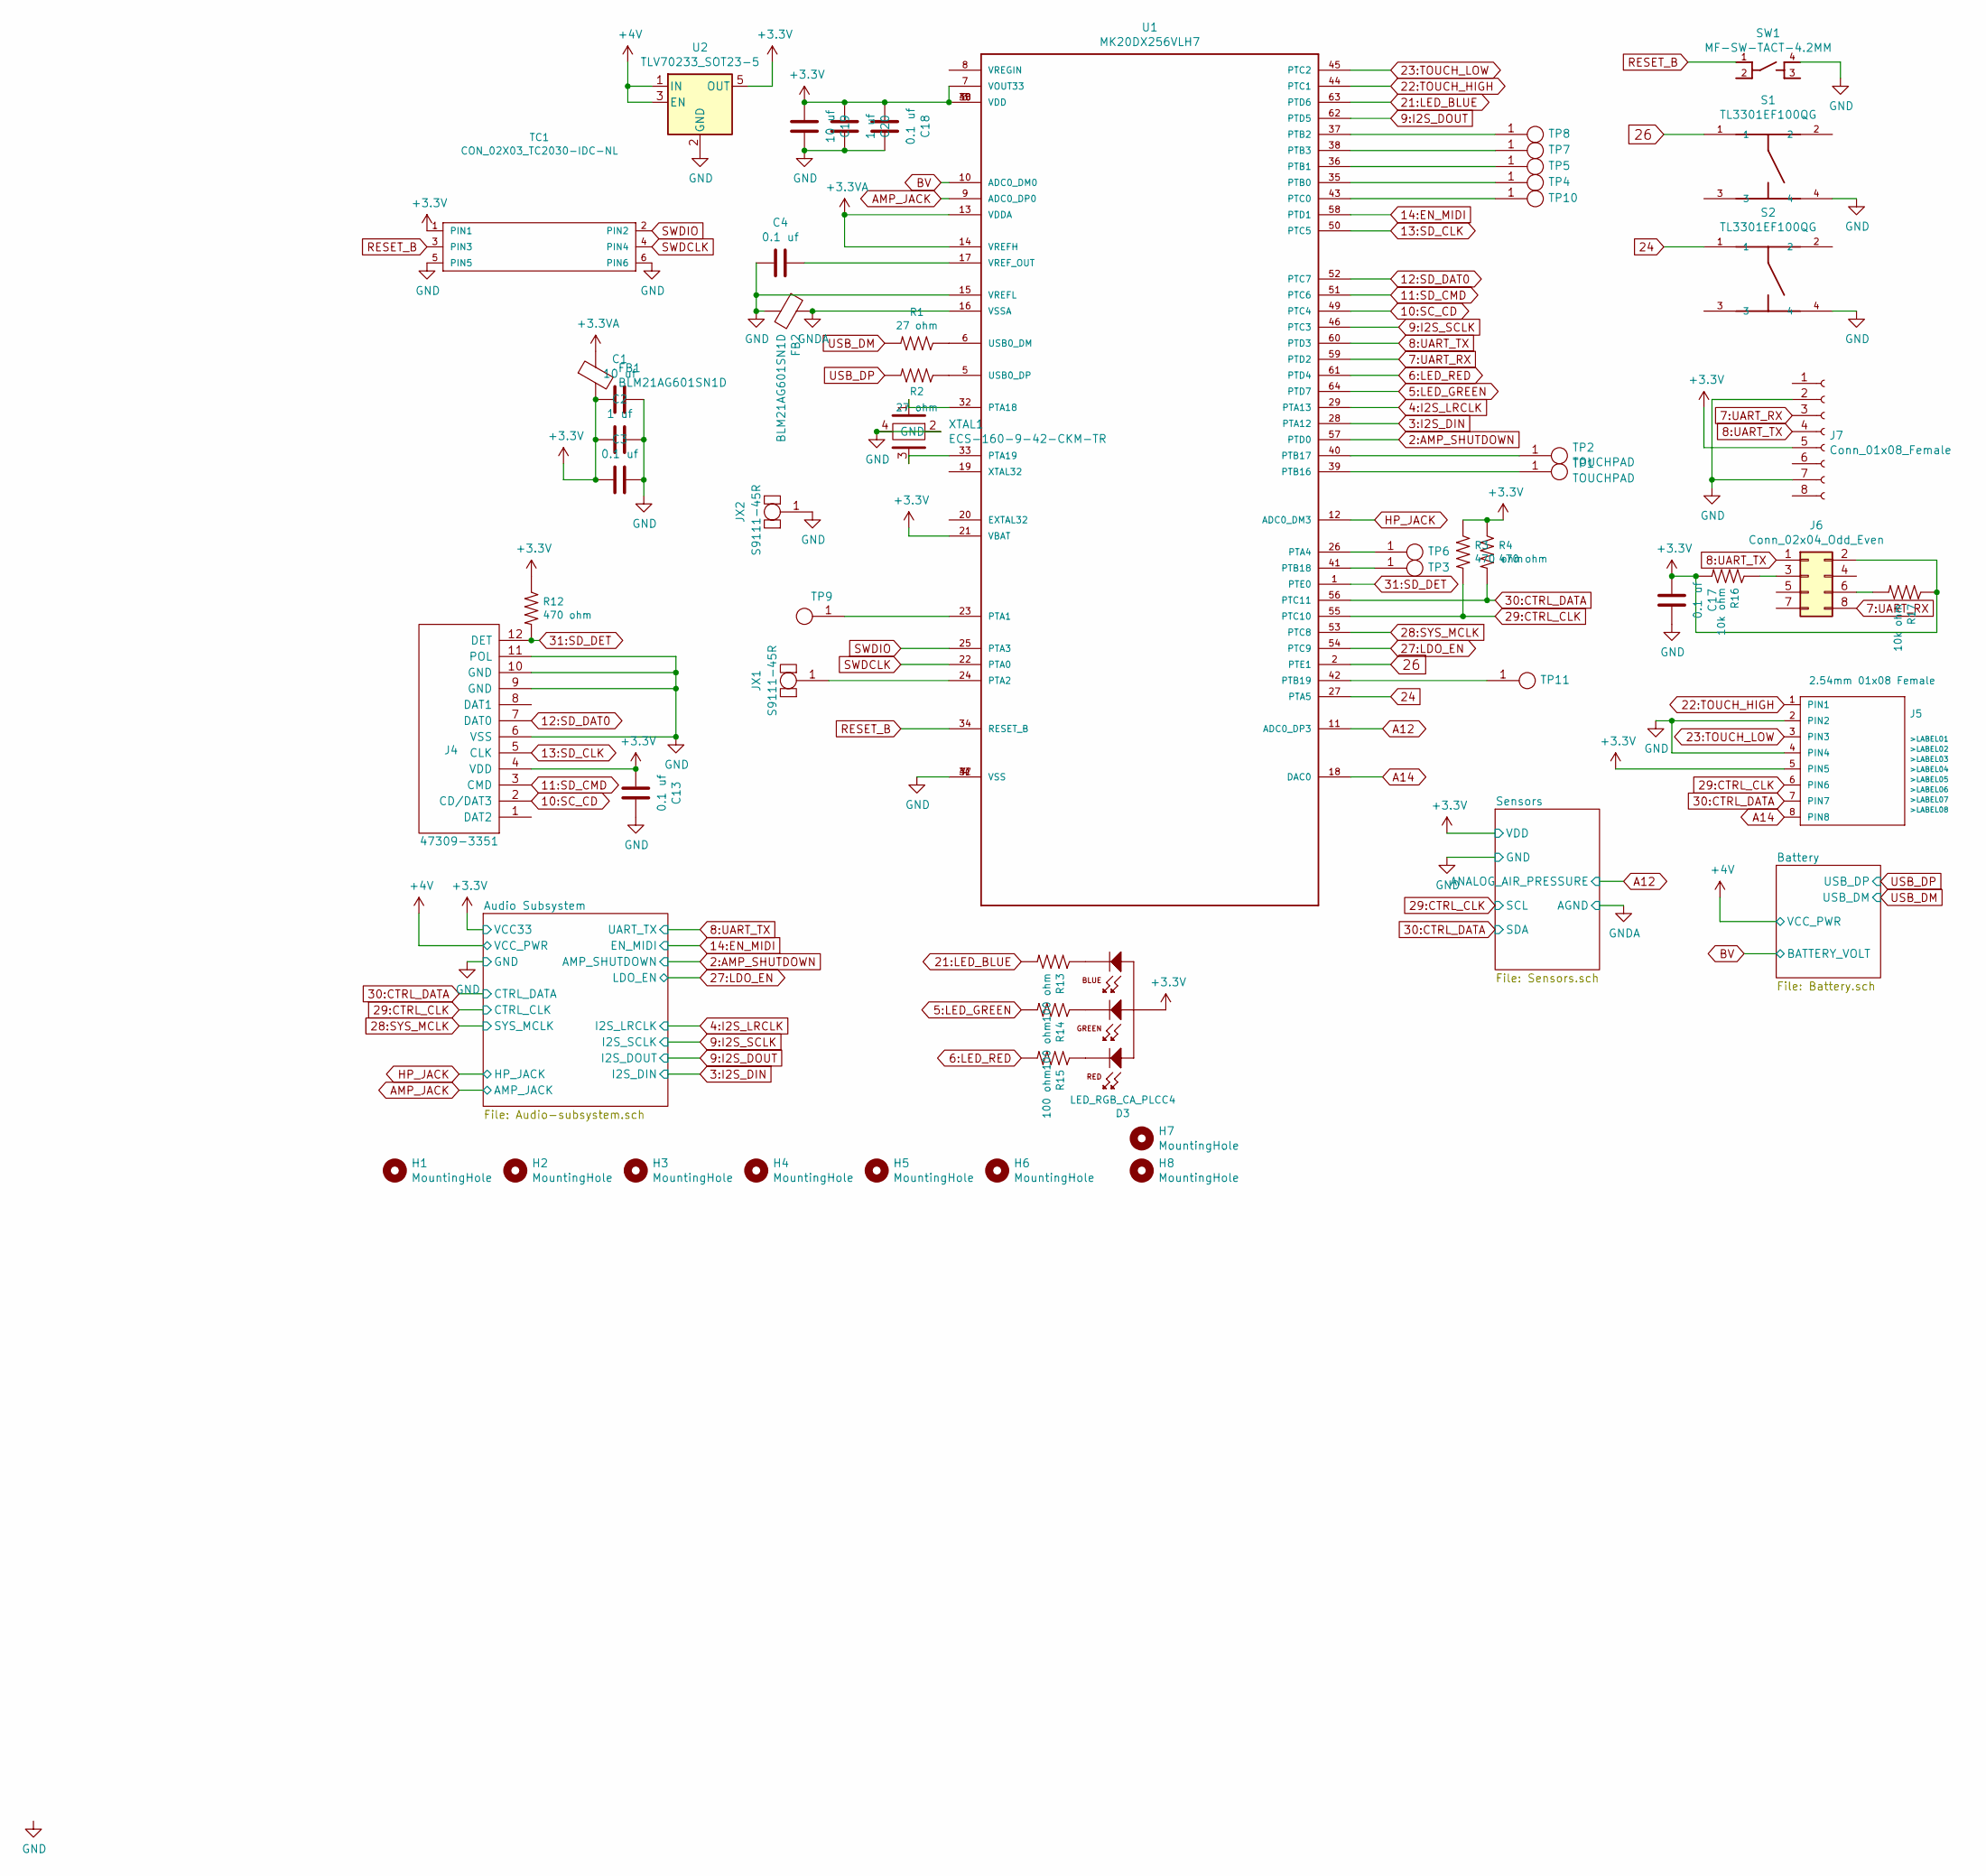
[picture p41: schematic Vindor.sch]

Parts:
C1, C19: 10 uf; MF_Passives-C1206; MPN MF-CAP-1206-10uF
C2, C20: 1 uf; MF_Passives-C0603; MPN MF-CAP-0603-1uF
C3, C4, C13, C17, C18: 0.1 uf; MF_Passives-C0603; MPN MF-CAP-0603-0.1uF
D3: LED_RGB_CA_PLCC4; MF_LEDs-PLCC4; MPN MF-LED-ASMB-RGB
FB1, FB2: BLM21AG601SN1D; L_0805_2012Metric; MPN 742792040
H1, H2, H3, H4, H5, H6, H7: MountingHole; Screw_hole
H8: MountingHole; Vindor_light_pipe
J4: 47309-3351; MOLEX_MICROSD_473093351; MPN 47309-3351
J5: 2.54mm 01x08 Female; MF_Connectors-PTH_2.54MM_01X08; MPN PPTC081LFBN-RC
J6: Conn_02x04_Odd_Even; PinHeader_2x04_P2.54mm_Vertical
J7: Conn_01x08_Female; MF_Connectors-PTH_2.54MM_01X08
JX1: S9111-45R; HARWIN_S9111_45R; MPN S9111-45R
JX2: S9111-45R; HARWIN_S9111_45R-TIGHT; MPN S9111-45R
R1, R2: 27 ohm; MF_Passives-R0603; MPN MF-RES-0603-27
R3, R12: 470 ohm; MF_Passives-R0603; MPN MF-RES-0603-470
R4: 470 ohm; MF_Passives-L0603; MPN MF-RES-0603-470
R13, R14, R15: 100 ohm; MF_Passives-R0603; MPN MF-RES-0603-100
R16, R17: 10k ohm; MF_Passives-L0603; MPN MF-RES-0603-10K
S1, S2: TL3301EF100QG; SOIC450P1000X730-4N; MPN TL3301SPF160QG
SW1: MF-SW-TACT-4.2MM; SW_PTS810_SJM_250_SMTR_LFS; MPN MF-SW-TACT-4.2MM
TC1: CON_02X03_TC2030-IDC-NL; TC2030
TP1, TP2, TP3, TP4, TP5, TP6, TP7, TP8, TP9, TP10, TP11: TOUCHPAD; Vindor_Touchpad
U1: MK20DX256VLH7; MPN MK20DX256VLH7
U2: TLV70233_SOT23-5; SOT-23-5; MPN MF-REG-SOT235-3.3V-300mA
XTAL1: ECS-160-9-42-CKM-TR; MPN ECS-160-9-42-CKM-TR

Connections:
2:AMP_SHUTDOWN: U1.57 (PTD0); also elsewhere on the board
3:I2S_DIN: U1.28 (PTA12); also elsewhere on the board
4:I2S_LRCLK: U1.29 (PTA13); also elsewhere on the board
5:LED_GREEN: R14.2, U1.64 (PTD7)
6:LED_RED: R15.2, U1.61 (PTD4)
7:UART_RX: J6.8, J7.3, U1.59 (PTD2)
8:UART_TX: J6.1, J7.4, U1.60 (PTD3); also elsewhere on the board
9:I2S_DOUT: U1.62 (PTD5); also elsewhere on the board
9:I2S_SCLK: U1.46 (PTC3); also elsewhere on the board
10:SC_CD: J4.2 (CD/DAT3), U1.49 (PTC4)
11:SD_CMD: J4.3 (CMD), U1.51 (PTC6)
12:SD_DAT0: J4.7 (DAT0), U1.52 (PTC7)
13:SD_CLK: J4.5 (CLK), U1.50 (PTC5)
14:EN_MIDI: U1.58 (PTD1); also elsewhere on the board
21:LED_BLUE: R13.2, U1.63 (PTD6)
22:TOUCH_HIGH: J5.1 (PIN1), U1.44 (PTC1)
23:TOUCH_LOW: J5.3 (PIN3), U1.45 (PTC2)
24: S2.1, U1.27 (PTA5)
26: S1.1, U1.2 (PTE1)
27:LDO_EN: U1.54 (PTC9); also elsewhere on the board
28:SYS_MCLK: U1.53 (PTC8); also elsewhere on the board
29:CTRL_CLK: J5.6 (PIN6), R3.2, U1.55 (PTC10); also elsewhere on the board
30:CTRL_DATA: J5.7 (PIN7), R4.2, U1.56 (PTC11); also elsewhere on the board
31:SD_DET: J4.12 (DET), R12.2, U1.1 (PTE0)
+3.3VA: FB1.1, U1.13 (VDDA), U1.14 (VREFH)
+4V: U2.1 (IN), U2.3 (EN); also elsewhere on the board
A12: U1.11 (ADC0_DP3); also elsewhere on the board
A14: J5.8 (PIN8), U1.18 (DAC0)
AMP_JACK: U1.9 (ADC0_DP0); also elsewhere on the board
BV: U1.10 (ADC0_DM0); also elsewhere on the board
GNDA: FB2.1, U1.16 (VSSA); also elsewhere on the board
HP_JACK: U1.12 (ADC0_DM3); also elsewhere on the board
LGND: C1.1, C2.1, C3.1, C4.2, C13.1, C17.1, C18.1, C19.1, C20.1, FB2.2, J4.6 (VSS), J4.9 (GND), J4.10 (GND), J4.11 (POL), J5.2 (PIN2), J5.4 (PIN4), J7.2, J7.7, JX2.1, S1.4, S2.4, SW1.4, TC1.5 (PIN5), TC1.6 (PIN6), U1.4 (VSS), U1.15 (VREFL), U1.31 (VSS), U1.47 (VSS), U2.2 (GND), XTAL1.2, XTAL1.4 (GND); also elsewhere on the board
unnamed: C4.1, U1.17 (VREF_OUT)
unnamed: D3.2 (CATHODE_RED), R15.1
unnamed: D3.3 (CATHODE_GREEN), R14.1
unnamed: D3.4 (CATHODE_BLUE), R13.1
unnamed: J6.3, R16.1
unnamed: J6.6, R17.2
unnamed: JX1.1, U1.24 (PTA2)
unnamed: R1.1, U1.6 (USB0_DM)
unnamed: R2.1, U1.5 (USB0_DP)
unnamed: TP1.1, U1.39 (PTB16)
unnamed: TP2.1, U1.40 (PTB17)
unnamed: TP3.1, U1.41 (PTB18)
unnamed: TP4.1, U1.35 (PTB0)
unnamed: TP5.1, U1.36 (PTB1)
unnamed: TP6.1, U1.26 (PTA4)
unnamed: TP7.1, U1.38 (PTB3)
unnamed: TP8.1, U1.37 (PTB2)
unnamed: TP9.1, U1.23 (PTA1)
unnamed: TP10.1, U1.43 (PTC0)
unnamed: TP11.1, U1.42 (PTB19)
unnamed: U1.32 (PTA18), XTAL1.1
unnamed: U1.33 (PTA19), XTAL1.3
RESET_B: SW1.1, TC1.3 (PIN3), U1.34 (RESET_B)
SWDCLK: TC1.4 (PIN4), U1.22 (PTA0)
SWDIO: TC1.2 (PIN2), U1.25 (PTA3)
USB_DM: R1.2; also elsewhere on the board
USB_DP: R2.2; also elsewhere on the board
VCC33: C1.2, C2.2, C3.2, C13.2, C17.2, C18.2, C19.2, C20.2, D3.1 (ANODE), FB1.2, J4.4 (VDD), J5.5 (PIN5), J6.2, J7.5, R3.1, R4.1, R12.1, R16.2, R17.1, TC1.1 (PIN1), U1.3 (VDD), U1.7 (VOUT33), U1.21 (VBAT), U1.30 (VDD), U1.48 (VDD), U2.5 (OUT); also elsewhere on the board

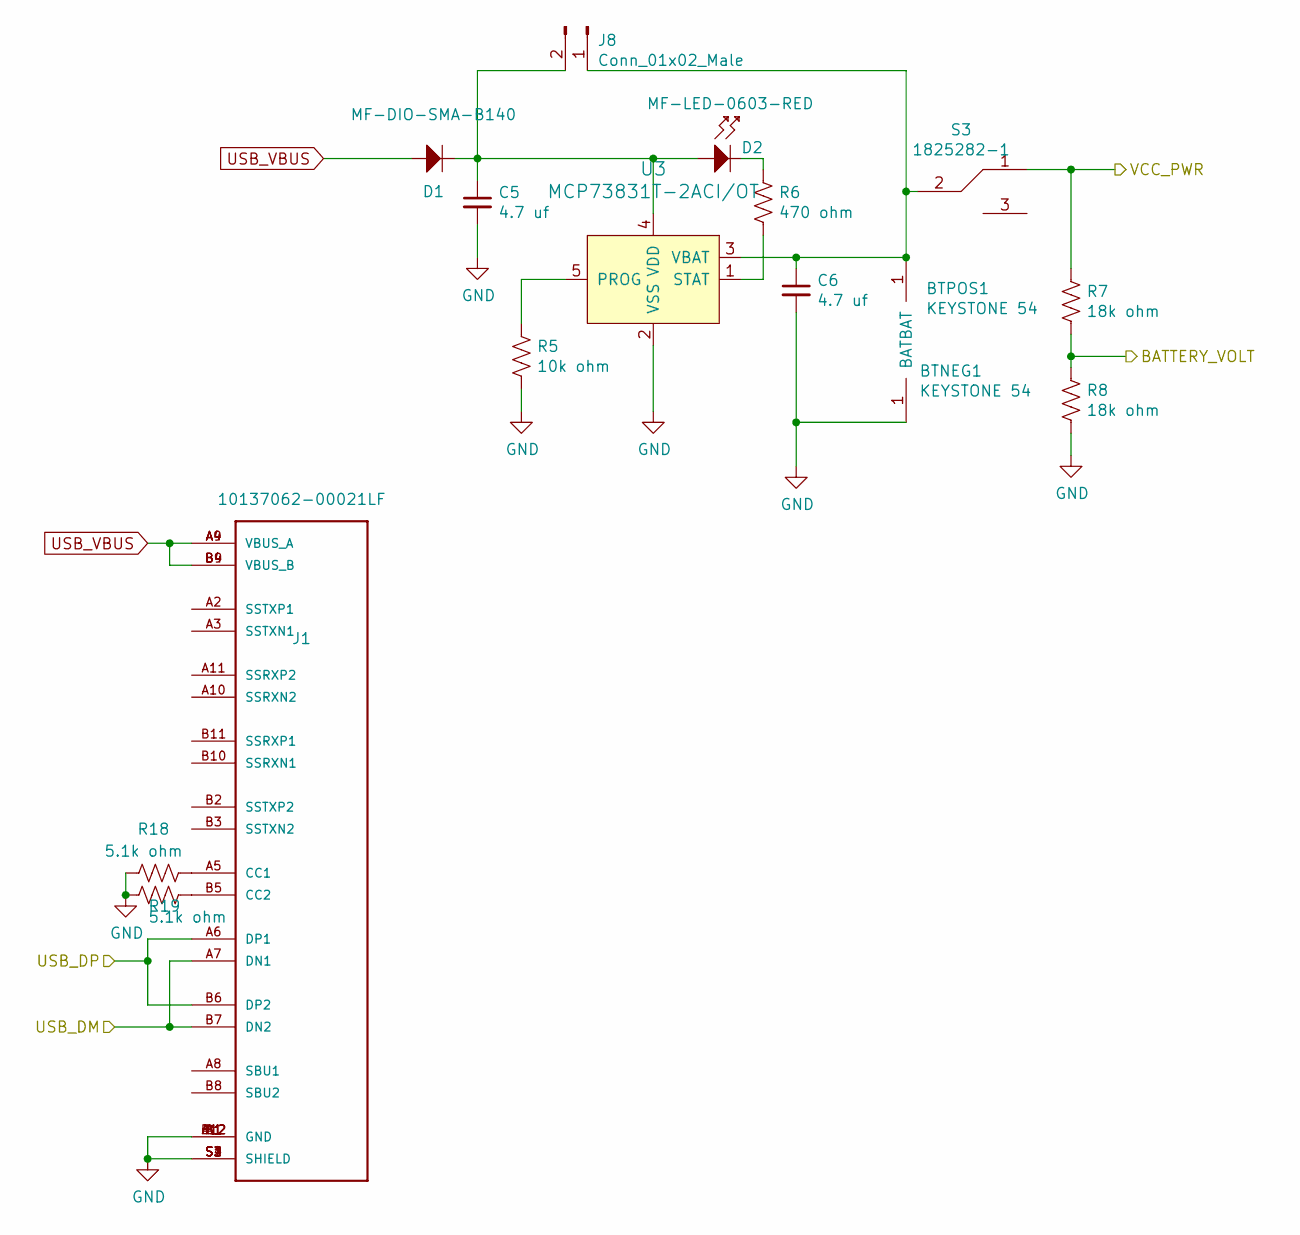
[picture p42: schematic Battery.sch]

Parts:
BTNEG1: KEYSTONE 54; KEYSTONE_54; MPN Keystone 54
BTPOS1: KEYSTONE 54; KEYSTONE_54; MPN Keystone 54
C5, C6: 4.7 uf; MF_Passives-C0603; MPN CL10A475KQ8NNNC
D1: MF-DIO-SMA-B140; MF_Discrete_Semiconductor-SMA; MPN MF-DIO-SMA-B140
D2: MF-LED-0603-RED; MF_LEDs-LED0603; MPN MF-LED-0603-RED
J1: 10137062-00021LF; USBC_10137062-00021LF; MPN 10137062-00021LF
J8: Conn_01x02_Male; MF_Connectors-PTH_2.54MM_01X02
R5: 10k ohm; MF_Passives-R0603; MPN MF-RES-0603-10K
R6: 470 ohm; MF_Passives-R0603; MPN MF-RES-0603-470
R7, R8: 18k ohm; MF_Passives-R0603; MPN MF-RES-0603-18K
R18, R19: 5.1k ohm; MF_Passives-R0603; MPN RC0603JR-075K1L
S3: 1825282-1; TE1825282-1; MPN 1825282-1; Digi-Key_PN EG1903-ND
U3: MCP73831T-2ACI/OT; SOT-753; MPN MCP73831T-2ACI_OT; Digi-Key_PN MCP73831T-2ACI/OTCT-ND

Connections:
+4V: R7.1, S3.1; also elsewhere on the board
BV: R7.2, R8.1; also elsewhere on the board
LGND: BTNEG1.1, C5.2, C6.2, J1.A1 (GND), J1.A12 (GND), J1.B1 (GND), J1.B12 (GND), J1.S1 (SHIELD), J1.S2 (SHIELD), J1.S3 (SHIELD), J1.S4 (SHIELD), R5.2, R8.2, R18.2, R19.2, U3.2 (VSS); also elsewhere on the board
unnamed: BTPOS1.1, C6.1, J8.1, S3.2, U3.3 (VBAT)
unnamed: C5.1, D1.CATH (CATHODE), D2.ANOD (ANODE), J8.2, U3.4 (VDD)
unnamed: D2.CATH (CATHODE), R6.1
unnamed: J1.A5 (CC1), R18.1
unnamed: J1.B5 (CC2), R19.1
unnamed: R5.1, U3.5 (PROG)
unnamed: R6.2, U3.1 (STAT)
USB_DM: J1.A7 (DN1), J1.B7 (DN2); also elsewhere on the board
USB_DP: J1.A6 (DP1), J1.B6 (DP2); also elsewhere on the board
USB_VBUS: D1.ANOD (ANODE), J1.A4 (VBUS_A), J1.A9 (VBUS_A), J1.B4 (VBUS_B), J1.B9 (VBUS_B)

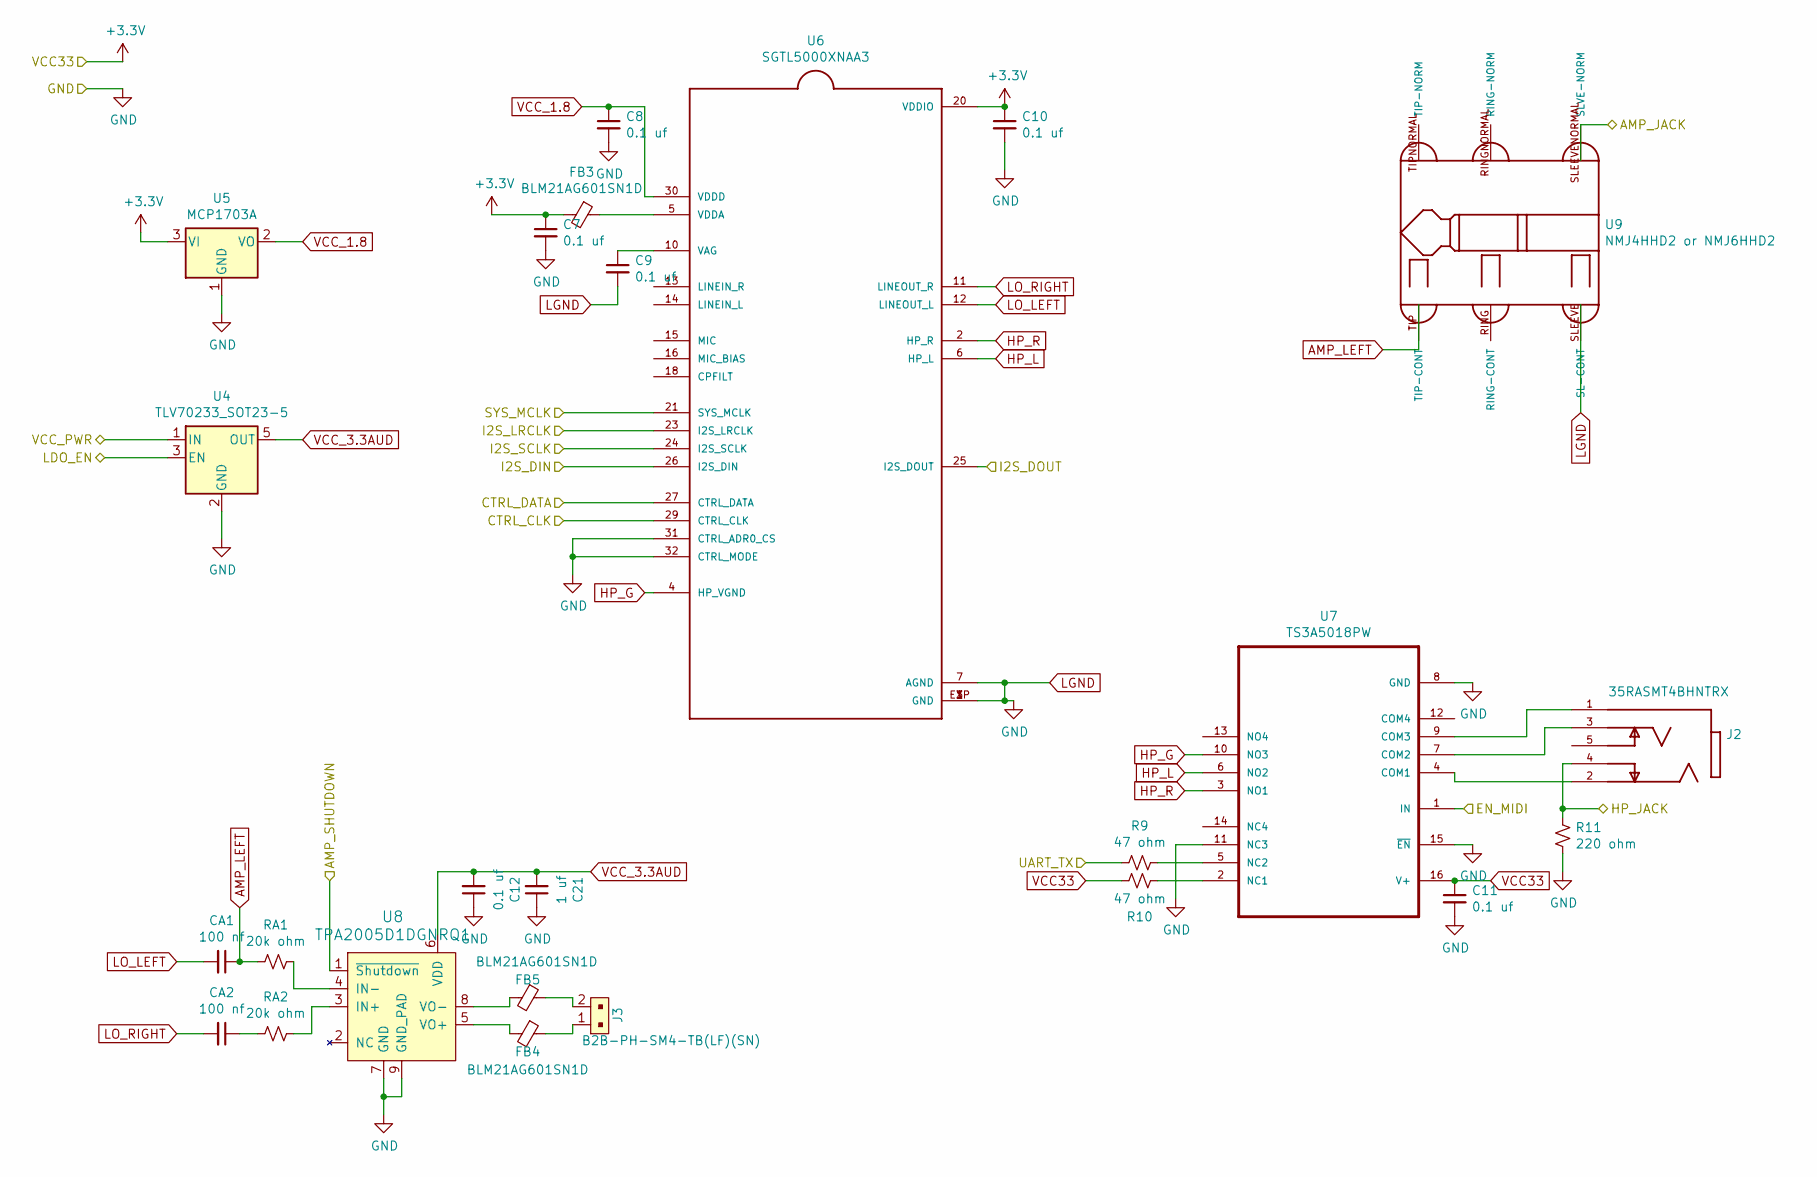
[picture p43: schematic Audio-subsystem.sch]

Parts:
C7, C8, C9, C10, C11, C12: 0.1 uf; MF_Passives-C0603; MPN MF-CAP-0603-0.1uF
C21: 1 uf; MF_Passives-C0603; MPN MF-CAP-0603-1uF
CA1, CA2: 100 nf; MF_Passives-C1210; MPN ECHU1C104JX5
FB3, FB4, FB5: BLM21AG601SN1D; MF_Passives-C0805; MPN BLM21AG601SN1D
J2: 35RASMT4BHNTRX; SWITCHCRAFT_35RASMT4BHNTRX; MPN 35RASMT4BHNTRX
J3: B2B-PH-SM4-TB(LF)(SN); PinHeader_1x2_P2mm; MPN B2B-PH-SM4-TB(LF)(SN); Digi-Key_PN 455-1734-1-ND
R9, R10: 47 ohm; MF_Passives-R0603; MPN MF-RES-0603-47
R11: 220 ohm; MF_Passives-R0603; MPN MF-RES-0603-220
RA1, RA2: 20k ohm; MF_Passives-R0603; MPN ERA-3AEB203V
U4: TLV70233_SOT23-5; SOT-23-5; MPN MF-REG-SOT235-3.3V-300mA
U5: MCP1703A; SOT-23; MPN MCP1703AT-1802E/CB
U6: SGTL5000XNAA3; SGTL5000; MPN SGTL5000XNAA3
U7: TS3A5018PW; SOP65P640X120-16N; MPN TS3A5018PW
U8: TPA2005D1DGNRQ1; Vindor-MSOP-8-1EP_W3mm; MPN TPA2005D1DGNRQ1; Digi-Key_PN 296-24831-1-ND
U9: NMJ4HHD2 or NMJ6HHD2; NMJ6HFD2-center; MPN NMJ4HHD2

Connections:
2:AMP_SHUTDOWN: U8.1 (~Shutdown); also elsewhere on the board
3:I2S_DIN: U6.26 (I2S_DIN); also elsewhere on the board
4:I2S_LRCLK: U6.23 (I2S_LRCLK); also elsewhere on the board
8:UART_TX: R9.2; also elsewhere on the board
9:I2S_DOUT: U6.25 (I2S_DOUT); also elsewhere on the board
9:I2S_SCLK: U6.24 (I2S_SCLK); also elsewhere on the board
14:EN_MIDI: U7.1 (IN); also elsewhere on the board
27:LDO_EN: U4.3 (EN); also elsewhere on the board
28:SYS_MCLK: U6.21 (SYS_MCLK); also elsewhere on the board
29:CTRL_CLK: U6.29 (CTRL_CLK); also elsewhere on the board
30:CTRL_DATA: U6.27 (CTRL_DATA); also elsewhere on the board
+4V: U4.1 (IN); also elsewhere on the board
AMP_JACK: U9.SLEEVENORMAL (SLVE-NORM); also elsewhere on the board
AMP_LEFT: CA1.1, RA1.2, U9.TIP (TIP-CONT)
HP_G: U6.4 (HP_VGND), U7.10 (NO3)
HP_JACK: J2.4, R11.2; also elsewhere on the board
HP_L: U6.6 (HP_L), U7.6 (NO2)
HP_R: U6.2 (HP_R), U7.3 (NO1)
LGND: C7.2, C8.2, C9.2, C10.2, C11.2, C12.1, C21.1, R11.1, U4.2 (GND), U5.1 (GND), U6.1 (GND), U6.3 (GND), U6.7 (AGND), U6.31 (CTRL_ADR0_CS), U6.32 (CTRL_MODE), U6.EXP (GND), U7.8 (GND), U7.11 (NC3), U7.15 (~EN), U8.7 (GND), U8.9 (GND_PAD), U9.SLEEVE (SL-CONT); also elsewhere on the board
LO_LEFT: CA1.2, U6.12 (LINEOUT_L)
LO_RIGHT: CA2.2, U6.11 (LINEOUT_R)
unnamed: C9.1, U6.10 (VAG)
unnamed: CA2.1, RA2.2
unnamed: FB3.1, U6.5 (VDDA)
unnamed: FB4.1, J3.1
unnamed: FB4.2, U8.5 (VO+)
unnamed: FB5.1, J3.2
unnamed: FB5.2, U8.8 (VO-)
unnamed: J2.1, U7.9 (COM3)
unnamed: J2.2, U7.4 (COM1)
unnamed: J2.3, U7.7 (COM2)
unnamed: R9.1, U7.5 (NC2)
unnamed: R10.1, U7.2 (NC1)
unnamed: RA1.1, U8.4 (IN-)
unnamed: RA2.1, U8.3 (IN+)
VCC33: C7.1, C10.1, C11.1, FB3.2, R10.2, U5.3 (VI), U6.20 (VDDIO), U7.16 (V+); also elsewhere on the board
VCC_1.8: C8.1, U5.2 (VO), U6.30 (VDDD)
VCC_3.3AUD: C12.2, C21.2, U4.5 (OUT), U8.6 (VDD)

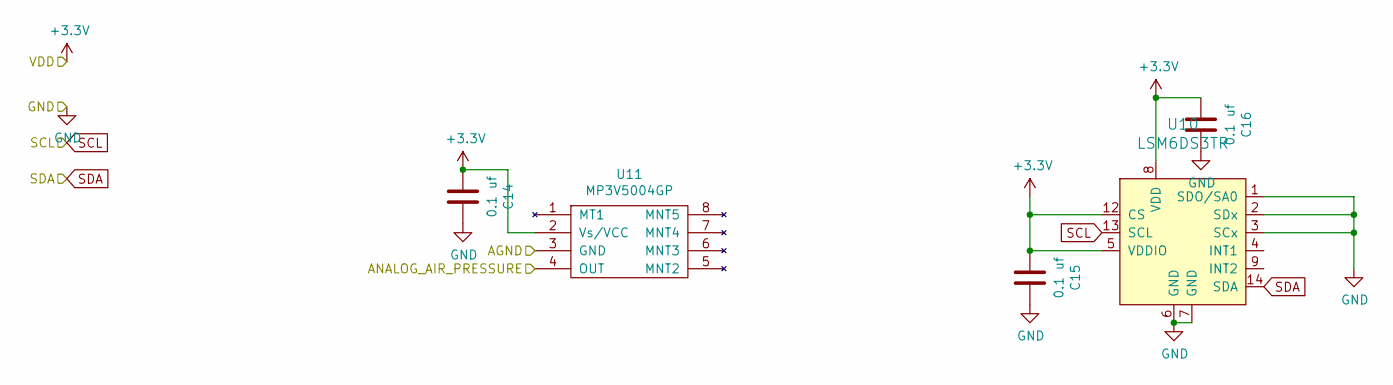
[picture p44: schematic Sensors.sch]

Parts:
C14, C15, C16: 0.1 uf; MF_Passives-C0603; MPN MF-CAP-0603-0.1uF
U10: LSM6DS3TR; LGA-14_3x2.5mm_P0.5mm; MPN LSM6DS3TR; Digi-Key_PN 497-15383-1-ND
U11: MP3V5004GP; MPN MP3V5004GP

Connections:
29:CTRL_CLK: U10.13 (SCL); also elsewhere on the board
30:CTRL_DATA: U10.14 (SDA); also elsewhere on the board
A12: U11.4 (OUT); also elsewhere on the board
GNDA: U11.3 (GND); also elsewhere on the board
LGND: C14.1, C15.1, C16.1, U10.1 (SDO/SA0), U10.2 (SDx), U10.3 (SCx), U10.6 (GND), U10.7 (GND); also elsewhere on the board
VCC33: C14.2, C15.2, C16.2, U10.5 (VDDIO), U10.8 (VDD), U10.12 (CS), U11.2 (Vs/VCC); also elsewhere on the board

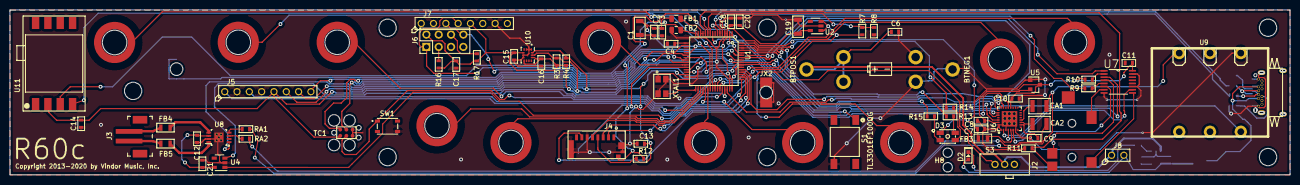
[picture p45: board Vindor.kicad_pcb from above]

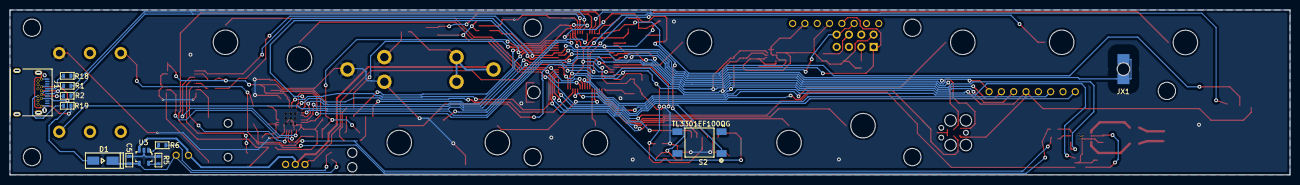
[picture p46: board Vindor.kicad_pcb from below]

Board: 2 copper layers, 264.0 x 34.0 mm, 100 parts (12 on the bottom side), 91 nets.

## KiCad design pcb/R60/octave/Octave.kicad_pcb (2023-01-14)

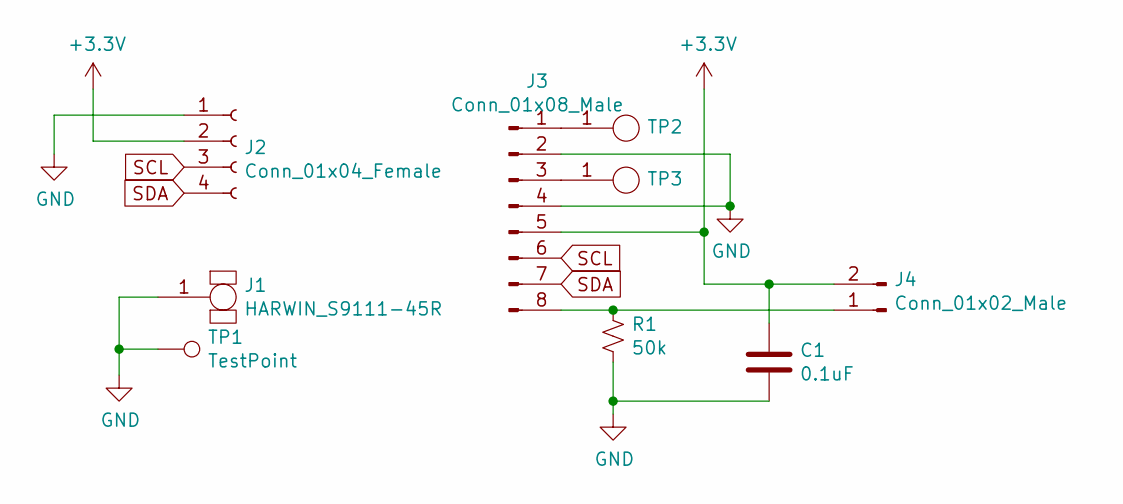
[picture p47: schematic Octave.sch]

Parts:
C1: 0.1uF; MF_Passives-C0603; MPN MF-CAP-0603-0.1uF
J1: HARWIN_S9111-45R; HARWIN_S9111_45R; MPN S9111-45
J2: Conn_01x04_Female; Moldex-0448120004; MPN 44812-0004
J3: Conn_01x08_Male; PinHeader_1x08_P2.54mm_Vertical; MPN MF-CON-2.54mm-01x08
J4: Conn_01x02_Male; JST_PH_S2B-PH-K_1x02_P2.00mm_Horizontal; MPN S2B-PH-K-S(LF)(SN)
R1: 50k; MF_Passives-R0603; MPN MF-RES-0603-50K
TP1: TestPoint; PinHeader_1x01_P2.54mm_Horizontal
TP2, TP3: TOUCHPAD; Vindor_Touchpad

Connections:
+3V3: C1.1, J2.2, J3.5, J4.2
GND: C1.2, J1.1, J2.1, J3.2, J3.4, R1.1, TP1.1
unnamed: J3.1, TP2.1
unnamed: J3.3, TP3.1
unnamed: J3.8, J4.1, R1.2
SCL: J2.3, J3.6
SDA: J2.4, J3.7

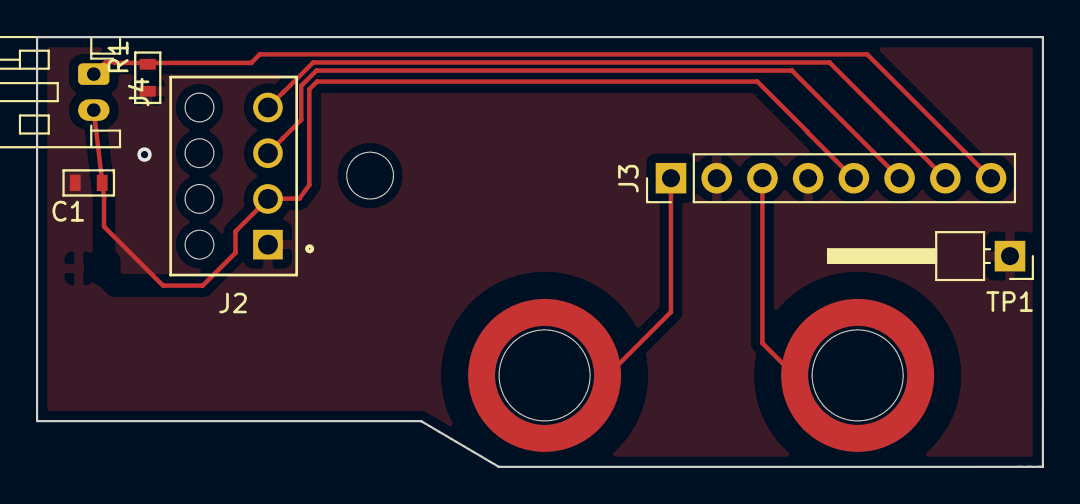
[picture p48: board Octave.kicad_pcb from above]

Board: 2 copper layers, 55.9 x 23.9 mm, 9 parts (1 on the bottom side), 7 nets.

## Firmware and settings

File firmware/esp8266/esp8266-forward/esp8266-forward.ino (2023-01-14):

// These need to be included when using standard Ethernet
#include <ESP8266WiFi.h>
#include <ESP8266mDNS.h>

#include <WiFiClient.h>
#include <WiFiUdp.h>
#include <Dns.h>

#include "AppleMidi.h"

const char *host = "vindores1";
const char *ver = "ESP8266-R1";

int set_wifi = 0;
char ssid[128];
char pass[128];

unsigned long t0 = millis();
bool isConnected = false;

APPLEMIDI_CREATE_INSTANCE(WiFiUDP, AppleMIDI); // see definition in AppleMidi_Defs.h

String readLine(WiFiClient &client) {
  String ret;
  char c, c2;
  while(client.available()) {
    c = client.read();
    if (c == '\r' || c == '\n') break;
    ret += c;
  }
  c2 = client.peek();
  if (c == '\r' && c2 == '\n') client.read();
  if (c == '\n' && c2 == '\r') client.read();
  return ret;
}

String getDate(int debug=0) {
  const char* host = "google.com";
  const char* url   = "/";
//  const char* host = "currentmillis.com";
//  const char* url   = "/time/minutes-since-unix-epoch.php";

  String now("None");

// Use WiFiClient class to create TCP connections
  WiFiClient client;
  const int httpPort = 80;
  if (!client.connect(host, httpPort)) {
    if (debug) Serial.println("connection failed");
    now = "Connection failed";
    return now;
  }
  
  if (debug) {
    Serial.print("Requesting URL: ");
    Serial.println(url);
  }
  
  // This will send the request to the server
  client.print(String("GET ") + url + " HTTP/1.1\r\n" +
               "Host: " + host + "\r\n" + 
               "Connection: close\r\n\r\n");
  unsigned long timeout = millis();
  while (client.available() == 0) {
    if (millis() - timeout > 5000) {
      if (debug) Serial.println(">>> Client Timeout !");
      client.stop();
      now = "Request timeout";
      return now;
    }
  }

  int data = 0;
  
  // Read all the lines of the reply from server and print them to Serial
  while(client.available()){
    String line = readLine(client);
    if (! data) {
      if (line.length() == 0) {
        if (debug) Serial.println("SRDDATA");
        data = 1; 
        continue;
      }
      if (line.startsWith("Date: ")) {
        now = line.substring(6);
      }
    }
    if (debug) Serial.print("!");
    if (debug) Serial.print(line);
    if (debug) Serial.println("!");
  }
  
  return now;
}

// -----------------------------------------------------------------------------
//
// -----------------------------------------------------------------------------
void initConnect()
{
  Serial.print("SRDCONNECT:");
  Serial.print(ssid);
  Serial.print(",");
  Serial.println(pass);
  WiFi.hostname(host);
  WiFi.begin(ssid, pass);
}

int service_connect = 0;
int service_time = 1;

void findService() {
  if (service_connect) return;
  if (service_time == 0) return;
  if (millis() < service_time) return;
  
  int n = MDNS.queryService("apple-midi", "udp");
  if (n == 0) {
#if 0
    Serial.println("SRDno services found");
#endif
    service_time = millis() + 2000;
  }
  else {
#if 0
    Serial.print(n);
    Serial.println(" service(s) found");
#endif
    for (int i = 0; i < n; ++i) {
      // Print details for each service found
#if 0
      Serial.print(i + 1);
      Serial.print(": ");
      Serial.print(MDNS.hostname(i));
      Serial.print(" (");
      Serial.print(MDNS.IP(i));
      Serial.print(":");
      Serial.print(MDNS.port(i));
      Serial.println(")");
#endif
      int port = 5004;
      if (MDNS.port(i) > 1) {
        port = MDNS.port(i);
      }
      if (MDNS.IP(i)==IPAddress(0,0,0,0)) {
        int r;
        char host[256];
        MDNS.hostname(i).toCharArray(host, 256);
        IPAddress ip;
        r = WiFi.hostByName(host, ip);
        if (r!=0) {
          AppleMIDI.invite(ip, port);
#if 0
          Serial.print("Invite ");
          Serial.print(host);
          Serial.print(":");
          Serial.println(ip);
#endif
        }      
      }
      else {
#if 0
        Serial.print("Invite ");
        Serial.println(MDNS.IP(i));
#endif
        AppleMIDI.invite(MDNS.IP(i), port);
      }
      service_connect = 1;
    }
  }
}

int wifi_init = 0;

int testConnect() {
  if (set_wifi == 0) return 0;
  if (wifi_init) return 1;
  if (WiFi.status() != WL_CONNECTED) return 0;
  wifi_init = 1;
  
  // Create a session and wait for a remote host to connect to us
  AppleMIDI.begin("vindor-midi-session");

  if (!MDNS.begin("vindor-midi")) {
//    Serial.println("Error setting up MDNS responder!");
  }
  MDNS.addService("apple-midi", "udp", 5004);

  AppleMIDI.OnConnected(OnAppleMidiConnected);
  AppleMIDI.OnDisconnected(OnAppleMidiDisconnected);

  AppleMIDI.OnReceiveNoteOn(OnAppleMidiNoteOn);
  AppleMIDI.OnReceiveNoteOff(OnAppleMidiNoteOff);
  AppleMIDI.OnReceiveControlChange(OnAppleMidiControlChange);
  AppleMIDI.OnReceiveSystemExclusive(OnAppleMidiSystemExclusive);
//  AppleMIDI.OnReceiveAfterTouchChannel(OnAppleMidiAfterTouchChannel);
//  AppleMIDI.OnReceiveAfterTouchPoly(OnAppleMidiAfterTouchPoly);
  
  findService();
//  service_time = 1;
  
  return 1;
}

int timex;

#define DBG1

#ifdef OTA

#include <ESP8266HTTPUpdateServer.h>
#include <ESP8266WebServer.h>

ESP8266HTTPUpdateServer httpUpdater;
ESP8266WebServer httpServer;

void startOTAService() {
  #ifdef DBG1
  strcpy(ssid, "gw2");
  strcpy(pass, "elephant");
  set_wifi = 1;
//  delay(1000);
  initConnect();
//  delay(2000);
  #endif

  MDNS.begin(host);
  httpUpdater.setup(&httpServer);
  httpServer.begin();
  MDNS.addService("http", "tcp", 80);
}

#endif

void setup() {
  // Serial communications and wait for port to open:
  #ifdef DBG1
  Serial.begin(115200);
  #else
  Serial.begin(31250);
  #endif
  timex = millis();
  Serial.println("SRDBEGIN");
  #ifdef OTA
  startOTAService();
  #endif
}

int getByte() {
  int timeout = millis()+1000;
  while(Serial.available() == 0) {
    if (millis() > timeout) return -1;
  }
  return Serial.read();
}

int inByte;
int cmd;

uint8_t buffer[256];
int idx = 0;
int count = -1;

const int sleepSec = 60 * 60; // one hour

void process_special() {
  int c2 = buffer[1];
  if (c2 == 0x01) { // set ssid
    int len = buffer[2];
    strncpy(ssid, (char*)buffer+3, len);
    ssid[len] = 0;
  }
  if (c2 == 0x02) { // set pass
    int len = buffer[2];
    strncpy(pass, (char*)buffer+3, len);
    pass[len] = 0;
  }
  if (c2 == 0x03) { // connect
    set_wifi = 1;
    initConnect();
  }
  if (c2 == 0x04) { // revision
    Serial.print("SRV");
    Serial.println(ver);
  }
  if (c2 == 0x06) { // sleep
    ESP.deepSleep(0); // (sleepSec * 1000000);
  }
  if (c2 == 0x07) { // speed up
    Serial.begin(115200);
  }
}

void process() {
  int note, velocity, channel;
//  int cmdx = buffer[0] & 0xF0;
  channel = (buffer[0] & 0x0F) + 1;
  switch(cmd) {
    case 0x90: // NoteOn
      note = buffer[1];
      velocity = buffer[2];
      AppleMIDI.noteOn(note, velocity, channel);
      break;
    case 0x80: // NoteOff
      note = buffer[1];
      velocity = buffer[2];
      AppleMIDI.noteOff(note, velocity, channel);
      break;
    case 0xB0: // Control (BC, Expr, etc.)
      note = buffer[1];
      velocity = buffer[2];
      AppleMIDI.controlChange(note, velocity, channel);
      break;
    case 0xD0: // After touch channel
      velocity = buffer[1];
      AppleMIDI.afterTouch(velocity, channel);
      break;
    case 0xA0: // After touch poly
      note = buffer[1];
      velocity = buffer[2];
      AppleMIDI.polyPressure(note, velocity, channel);
      break;
    case 0xF0: // SysEx
      if (buffer[0] == 0xF0) {
        AppleMIDI.sysEx(idx+1, buffer, true);
      }
      else {
        process_special();      
      }
      break;
  }
  idx = 0;
  count = 0;
  cmd = 0;
}

int bytecount = 0;

// -----------------------------------------------------------------------------
//
// -----------------------------------------------------------------------------
void loop()
{  
  if (testConnect()) AppleMIDI.run();

#ifdef OTA
  httpServer.handleClient();
#endif

  //findService();

#if 1
  if (millis() - timex > 1000) {
//    pinMode(2, INPUT);
//    int x = digitalRead(2);
//    if (x) Serial.write("H");
//    else Serial.write("L");
    Serial.write('S');
    if (wifi_init) Serial.write('W');
    else Serial.write('X');
    if (isConnected) Serial.write('1');
    else Serial.write("0");
    timex = millis();

    AppleMIDI.activeSensing();

    static int cc = 0;
    if (cc++ > 10) {
      Serial.print("SRDping:");
      Serial.println(bytecount);
      cc=0;
    }

//    Serial.printf("SRDS%d\n", WiFi.status());
  }
#endif

  if (Serial.available() > 0) {
    bytecount++;
    int inByte = Serial.read();
    if (count > 0) {
      buffer[++idx] = inByte;
      
      Serial.print("SRDGOT:");
      for(int i=0; i<idx; i++) {
        Serial.print(buffer[i], HEX);
      }
      Serial.println();
      
      if (--count == 0) process();
      else if (cmd == 0xF0) { // SysEx & Special
        if (inByte == 0xF7) { // end
          process();
        }
      }
    }
    else {
      Serial.print("SRDSTART:"); Serial.println(inByte);
      cmd = inByte & 0xF0;
      buffer[0] = inByte;
      idx = 0;
      switch(cmd) {
        case 0x90: // NoteOn
          count = 2;
          break;
        case 0x80: // NoteOff
          count = 2;
          break;
        case 0xB0: // Control (BC, Expr, etc.)
          count = 2;
          break;
        case 0xD0: // After touch channel
          count = 1;
          break;
        case 0xA0: // After touch poly
          count = 2;
          break;
        case 0xF0: // SysEx & Custom
          count = sizeof(buffer);
          break;
        default:
          Serial.print("SRDUNK:");
          Serial.println(cmd, HEX);
          break;
      }
    }
  }
}

// ====================================================================================
// Event handlers for incoming MIDI messages
// ====================================================================================

// -----------------------------------------------------------------------------
// rtpMIDI session. Device connected
// -----------------------------------------------------------------------------
void OnAppleMidiConnected(uint32_t ssrc, char* name) {
  isConnected  = true;
}

// -----------------------------------------------------------------------------
// rtpMIDI session. Device disconnected
// -----------------------------------------------------------------------------
void OnAppleMidiDisconnected(uint32_t ssrc) {
  isConnected  = false;
}

// -----------------------------------------------------------------------------
//
// -----------------------------------------------------------------------------
void OnAppleMidiNoteOn(byte channel, byte note, byte velocity) {
  Serial.write(0x80 + (channel-1));
  Serial.write(note);
  Serial.write(velocity);
#if 0
  Serial.print("Incoming NoteOn from channel:");
  Serial.print(channel);
  Serial.print(" note:");
  Serial.print(note);
  Serial.print(" velocity:");
  Serial.print(velocity);
  Serial.println();
  Serial.write(0x90 + (channel-1));
  Serial.write(note);
  Serial.write(velocity);
#endif
}

// -----------------------------------------------------------------------------
//
// -----------------------------------------------------------------------------
void OnAppleMidiNoteOff(byte channel, byte note, byte velocity) {
  Serial.write(0x80 + (channel-1));
  Serial.write(note);
  Serial.write(velocity);
#if 0
  Serial.print("Incoming NoteOff from channel:");
  Serial.print(channel);
  Serial.print(" note:");
  Serial.print(note);
  Serial.print(" velocity:");
  Serial.print(velocity);
  Serial.println();
  Serial.write(0x80 + (channel-1));
  Serial.write(note);
  Serial.write(velocity);
#endif
}

void OnAppleMidiControlChange(byte channel, byte number, byte value) {
  Serial.write(0xB0 + (channel-1));
  Serial.write(number);
  Serial.write(value);
}

void OnAppleMidiSystemExclusive(byte *array, byte size) {
  if (array[0] != 0xF0) Serial.write(0xF0);
  for(int i=0; i<size; i++) {
    Serial.write(array[i]);
  }
  if (array[size-1] != 0xF7) Serial.write(0xF7);
}

void OnAppleMidiAfterTouchChannel(byte channel, byte pressure) {
  Serial.write(0xD0 + (channel-1));
  Serial.write(pressure);
}

void OnAppleMidiAfterTouchPoly(byte channel, byte note, byte pressure) {
  Serial.write(0xA0 + (channel-1));
  Serial.write(note);
  Serial.write(pressure);
}

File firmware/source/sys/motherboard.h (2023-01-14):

#define PIN_INTERNAL_REF 39

#ifdef PCB_R1_60c
#define ES2_LOGO
#define CPLATFORM 32
#define REVISION 60
#define DEVREV "R60"
#define SET_PIN 24   
// #define LIP_PRESSURE_PIN A14
#define BREATH_PIN A12
#define USEDAC
#define USE_SGTL5000
#define PIN_LAYOUT 9
#define PIN_BIS
#define SDCARD_CS 10
#define SDCARD_DETECT 31
#define AUDIOPLUG_PIN A13
#define LINEPLUG_PIN A10
#define LINEPLUG_PIN_ANALOG
#define LED_COMMON_ANODE
#define LED_RED_PIN 6
#define LED_GREEN_PIN 5
#define LED_BLUE_PIN 21
#define AMP_PIN 2
#define AUDIO_LDO_PIN 27
#define Uart Serial3
#define USE_UART
#define SWITCH_HP_MIDI_PIN 14
#define UART_SENSE_PIN_TX 8
#define UART_SENSE_PIN_RX 7
#define USE_DISPLAY
#define TOUCH_PAD_SPACE
#define ACC_LSM6DS3IMU
#define USE_ACCELEROMETER 26
#define USE_ACCELEROMETER_CS 31
#define PIN_BATTERY A11
#endif

#ifdef PCB_R1_60
#define ES2_LOGO
#define CPLATFORM 32
#define REVISION 60
#define DEVREV "R60"
#define SET_PIN 24   
// #define LIP_PRESSURE_PIN A14
#define BREATH_PIN A12
#define USEDAC
#define USE_SGTL5000
#define PIN_LAYOUT 9
#define PIN_BIS
#define SDCARD_CS 10
#define SDCARD_DETECT 31
#define AUDIOPLUG_PIN A13
#define LINEPLUG_PIN A10
#define LINEPLUG_PIN_ANALOG
#define LED_COMMON_ANODE
#define LED_RED_PIN 6
#define LED_GREEN_PIN 5
#define LED_BLUE_PIN 21
#define AMP_PIN 2
#define AUDIO_LDO_PIN 27
#define Uart Serial3
#define USE_UART
#define SWITCH_HP_MIDI_PIN 14
#define UART_SENSE_PIN_TX 8
#define UART_SENSE_PIN_RX 7
#define USE_DISPLAY
#define TOUCH_PAD_SPACE
#define ACC_LSM6DS3IMU
#define USE_ACCELEROMETER 26
#define USE_ACCELEROMETER_CS 31
#define PIN_BATTERY A11
#define AUDIO_RIGHLEFT_REVERSE_BUG
#endif

#ifdef PCB_R1_58
#define CPLATFORM 32
#define REVISION 58
#define DEVREV "R58"
#define SET_PIN 24   
#define LIP_PRESSURE_PIN A14
#define USE_AIR_MPRLS
#define USEDAC
#define USE_SGTL5000
#define PIN_LAYOUT 9
#define PIN_BIS
#define SDCARD_CS 10
#define SDCARD_DETECT 31
#define AUDIOPLUG_PIN A10
#define LINEPLUG_PIN A13
#define LED_COMMON_ANODE
#define LED_RED_PIN 6
#define LED_GREEN_PIN 5
#define LED_BLUE_PIN 21
#define AMP_PIN 2
#define AUDIO_LDO_PIN 27
#define Uart Serial3
#define USE_UART
#define SWITCH_HP_MIDI_PIN 14
#define UART_SENSE_PIN_TX 8
#define UART_SENSE_PIN_RX 7
#define USE_DISPLAY
// #define USE_VARIABLE_CHARGER
#define TOUCH_PAD_SPACE
// #define TOUCH_CALIB_HIGH
#define ACC_LSM6DS3IMU
#define USE_ACCELEROMETER 26
#define USE_ACCELEROMETER_CS 31
#define PIN_BATTERY A11
#endif

#ifdef PCB_R1_57
#define CPLATFORM 32
#define REVISION 57
#define DEVREV "R57"
#define SET_PIN 24   
#define LIP_PRESSURE_PIN A14
#define BREATH_PIN A12
#define USEDAC
#define USE_SGTL5000
#define PIN_LAYOUT 9
#define PIN_BIS
#define SDCARD_CS 10
#define AUDIOPLUG_PIN A10
#define LINEPLUG_PIN A13
#define LED_COMMON_ANODE
#define LED_RED_PIN 6
#define LED_GREEN_PIN 5
#define LED_BLUE_PIN 21
#define AMP_PIN 2
#define AUDIO_LDO_PIN 27
#define Uart Serial3
#define USE_UART
#define SWITCH_HP_MIDI_PIN 14
#define UART_SENSE_PIN_TX 8
#define UART_SENSE_PIN_RX 7
#define USE_DISPLAY
// #define USE_VARIABLE_CHARGER
#define TOUCH_PAD_SPACE
// #define TOUCH_CALIB_HIGH
#define ACC_LIS2HH12
#define USE_ACCELEROMETER 26
#define USE_ACCELEROMETER_CS 31
#define PIN_BATTERY A11
#endif

#ifdef PCB_R1_56
#define CPLATFORM 32
#define REVISION 56
#define DEVREV "R56"
#define SET_PIN 24   
#define BREATH_PIN A14
#define USEDAC
#define USE_SGTL5000
#define PIN_LAYOUT 9
#define PIN_BIS
#define SDCARD_CS 10
#define AUDIOPLUG_PIN A10
#define AUDIOPLUG_REVERSE
#define LINEPLUG_PIN 14
#define LED_COMMON_ANODE
#define LED_RED_PIN 6
#define LED_GREEN_PIN 5
#define LED_BLUE_PIN 21
#define AMP_PIN 2
#define AUDIO_LDO_PIN 27
#define Uart Serial3
#define USE_UART
#define UART_SENSE_PIN_TX 8
#define UART_SENSE_PIN_RX 7
#define USE_DISPLAY
#define USE_VARIABLE_CHARGER
#define TOUCH_PAD_SPACE
#define ACC_LIS2HH12
#define USE_ACCELEROMETER 26
#define USE_ACCELEROMETER_CS 31
#define PIN_BATTERY A11
#endif

#ifdef PCB_R1_53
#define CPLATFORM 32
#define REVISION 53
#define DEVREV "R53"
#define SET_PIN 24   
#define BREATH_PIN A14
#define USEDAC
#define USE_SGTL5000
#define PIN_LAYOUT 9
#define PIN_BIS
#define SDCARD_CS 10
#define AUDIOPLUG_PIN A10
#define LINEPLUG_PIN 14
#define LED_COMMON_ANODE
#define LED_RED_PIN 6
#define LED_GREEN_PIN 5
#define LED_BLUE_PIN 21
#define AMP_PIN 2
#define AUDIO_LDO_PIN 27
#define Uart Serial3
#define USE_UART
#define UART_SENSE_PIN_TX 8
#define UART_SENSE_PIN_RX 7
#define USE_DISPLAY
#define USE_VARIABLE_CHARGER
#define TOUCH_PAD_SPACE
#define ACC_ADXL362
#define USE_ACCELEROMETER 26
#define USE_ACCELEROMETER_CS 31
#define PIN_BATTERY A11
#endif
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

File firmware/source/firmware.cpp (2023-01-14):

/**
 * @file firmware.cpp
 * @author Fernando Trias
 * @brief 
 * @version 0.1
 * @date 2013
 * 
 * @copyright 2013-2021 by Fernando Trias
 * 
 */

// #include <i2c_t3.h>
#include "MyWire.h"
#include <EEPROM.h>
#ifdef USE_SDCARD
#include "SdLib.h"
#endif
#include <SPI.h>
#include <Audio.h>

#include "firmware.h"

#ifdef USBMIDI
#include <usb_desc.h>
#include <usb_dev.h>
#endif

#ifdef DEBUGTIMING
int time_slot;
long time_slot_millis[32];
const char *time_slot_name[32];
#endif

void power_off_device();

unsigned char *UID_REGISTER_ADDR = ((unsigned char *)0x40048054);
const int UID_REGISTER_LEN=16;
char cpu_guid[UID_REGISTER_LEN*2 + 1];

#ifdef SECURE_FLASH
__attribute__ ((section(".flashconfig"), used))
const uint8_t flashconfigbytes[16] = {
    0xFF, 0xFF, 0xFF, 0xFF, 0xFF, 0xFF, 0xFF, 0xFF, // No backdoor
    0xFF, 0xFF, 0xFF, 0xFF, // FPROT0-3, no protected pages
    // Backdoor disabled, Mass Erase enabled, NXP denied, Flash Secure
    0b01010111,
    0xF9,
    0xFF, 0xFF
};
#else
__attribute__ ((section(".flashconfig"), used))
const uint8_t flashconfigbytes[16] = {
    0x1F, 0xC2, 0x13, 0x4B, 0x83, 0x92, 0xAF, 0x29, // Backdoor
    0xFF, 0xFF, 0xFF, 0xFF, // FPROT0-3, no protected pages
    // Backdoor enabled, Mass Erase enabled, NXP access, Flash Unsecure
    0b10011110,
    0xF9,
    0xFF, 0xFF
};
#endif

#ifdef DEBUGDEV
unsigned int loopcount = 0;
#endif

int dispatchMidiId = -1;

enum InstrumentState {
    STATE_SILENCE,
    STATE_PRESS_DETECT,
    STATE_PLAY_START,
    STATE_PLAYING,
    STATE_PLAY_CHANGE,
    STATE_RELEASE_DETECT,
};

// used to stabalize air pressure for initial Velocity
const int PRESS_DEBOUNCE_MS = 10;
static InstrumentState state = STATE_SILENCE;


#include "fdebug.h"

#include "Constants.h"

#include "Settings.h"

SettingsData settings;

#include "LipPressure.h"
#include "Touch.h"
#include "SoundSynthesis.h"
// #include "sound.h"

#include "Boot.h"
#include "Lights.h"

#include "WatchDog.h"
#include "Dispatch.h"
#include "Power.h"
#include "ReadFingering.h"
#include "Pressure.h"
#include "OutputMode.h"
#include "Event.h"
#include "PlugState.h"
#include "Display.h"
#include "Diagnostic.h"
#include "Manage.h"

#ifdef USE_ACCELEROMETER
#include "Accelerometer.h"
#endif

#ifdef SAY_NUMBERS
#include "Speech.h"
#endif

#ifdef GPROF
#include "TeensyGProf.h"
#endif

#include "vdebug.h"

#ifdef SMALL_FOOTPRINT
#define GLOBAL_CONST const
#else
#define GLOBAL_CONST
#endif

const char *compile_time = __DATE__ " " __TIME__;

const int STARTNOTEPRESSURE = adc_read_scale * 0.003;  // minimum breath before note starts
const int STOPNOTEPRESSURE = 0;  // breath before note stops
const int WAKENOTEPRESSURE = adc_read_scale * 0.001;  // breath to turn on speaker

#ifdef SIMULATE
int simulate_on = 1;
#endif

/**
 * @brief Note processing parameters
 * 
 */

// state parameters

int playingNote = 0;
int playingOctave = 0;
int breathOnly = 0;
// int currentInstrument = -1;

int effect_flange = 0;
int effect_chorus = 0;

Lights led;
SoundSynthesis synth;
Pressure pressure;
OutputMode currentOutput;
WatchDog watchdog;
Dispatch dispatch;
ReadFingering fingering;
PlugState currentPlugState;

//
// Section for settings
//

void fatal_system_error(int code) {
    led.alloff();
#ifdef Uart
    Uart.begin(9600);
#endif
    while(1) {
#ifdef Uart
        Uart.println(code);
#endif
        for(int i=0; i<code; i++) {
            led.error(1);
            delay(200);
            led.error(0);
            delay(300);
        }
        delay(3000);
    }
}

void showMessage(const char *msg) {
#ifdef USE_DISPLAY
    Display::drawMessage(msg);
#endif
}

void power_off_device() {
    Power::setPeripherals(0);
    currentOutput.powerOff();
    led.alloff();
    synth.disable();
#ifdef USE_DISPLAY
    Display::displayOff();
#endif
    delay(100); // give time for powerdowns
#ifdef USE_SLEEP_MODE
    Power::powerDownCPU();
    delay(1000); // should never get here
    reboot();
#else
    #warn "Power down not enabled"
#endif
}

/************
 * 
 * Silence and idle time handling
 * 
 */

#ifdef SILENCESHUTDOWN

const int silenceStartTime = 10 * 1000; // ms before for simple power reduction
const int silenceQuietTime = 2 * 1000;

enum SilenceState {
    ACTIVE=0, QUIET=1, SILENT=2, IDLE=3
};

int silenceTime = 0;
SilenceState silenceState = ACTIVE;

void silenceInit() {
    silenceState = ACTIVE;
    silenceTime = millis();
}

void silenceEnd() {
    silenceTime = millis();
    if (silenceState == SILENT) {
        currentOutput.enableSilence(0);
    }
    silenceState = ACTIVE;
}

void silenceCheck() {
    if (silenceState==ACTIVE) {
        if ((millis() - silenceTime > silenceQuietTime)) {
            // TODO shut down simple devices
            silenceState = QUIET;
        }
        return;
    }
    if (silenceState==QUIET) {
        if ((millis() - silenceTime > silenceStartTime)) {
            silenceState = SILENT;
            currentOutput.enableSilence(1);
        }
        return;
    }
    if (silenceState==SILENT) {
        if  ((settings.idleSleep_ms) && (millis() - silenceTime > settings.idleSleep_ms)) { // long time inactive
            silenceState = IDLE;
            showMessage("IDLE OFF");
            led.error(1);
            delay(1000);
            power_off_device(); // doesn't return unless grave error
            // SHOULD NEVER GET HERE
            reboot();
        }
        return;
    }
}
#else
void silenceInit() {}
void silenceEnd() {}
void silenceCheck() {}
#endif


/************
 * 
 * Set a new instrument and reset the sound generation module
 * 
 */

void setinstrument(int inst) {
    // if (inst >= staticInstrumentNum) return;
    Event::eventNoteOff();
    bool rx = synth.stopWait();
    if (! rx) return; // couldn't stop play! ERROR!
    int midinum = synth.setInstrument(inst);
    Midi::midiProgramChange(midinum, settings.channel);
}

#ifdef SIMULATE

void compare_ram() {
    Serial.println("!!CHANGE!!");
    const int sz = 256;
    static uint32_t buffer[sz];
    static int first = 1;
    if (first) {first=0; return;}
    uint32_t *p = (uint32_t*)0x0000000020000dd0;
    for(int i=0;i<sz;i++) {
        if (buffer[i] != p[i]) {
            Serial.print((long)(p+i), HEX);
            Serial.print(" ");
            Serial.print(buffer[i]);
            Serial.print(" ");
            Serial.print(p[i]);
            Serial.println();
        }
    }
    for(int i=0;i<sz;i++) buffer[i] = p[i];
}

void dump_ram() {
    Serial.println("!!RAM!!");
    uint8_t *p = (uint8_t*)0x0000000020000dd0;
    for(int i=0;i<20;i++) {
        Serial.print((long)p, HEX);
        for(int j=0;j<16;j++) {
            Serial.print(" ");
            if (*p<16) Serial.print("0");
            Serial.print(*p, HEX);
            p++;
        }
        Serial.println();
    }
}
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

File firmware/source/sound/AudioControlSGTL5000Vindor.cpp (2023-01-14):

/* Audio Library for Teensy 3.X
 * Copyright (c) 2014, Paul Stoffregen, paul@pjrc.com
 *
 * Development of this audio library was funded by PJRC.COM, LLC by sales of
 * Teensy and Audio Adaptor boards.  Please support PJRC's efforts to develop
 * open source software by purchasing Teensy or other PJRC products.
 *
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
 * THE SOFTWARE IS PROVIDED "AS IS", WITHOUT WARRANTY OF ANY KIND, EXPRESS OR
 * IMPLIED, INCLUDING BUT NOT LIMITED TO THE WARRANTIES OF MERCHANTABILITY,
 * FITNESS FOR A PARTICULAR PURPOSE AND NONINFRINGEMENT. IN NO EVENT SHALL THE
 * AUTHORS OR COPYRIGHT HOLDERS BE LIABLE FOR ANY CLAIM, DAMAGES OR OTHER
 * LIABILITY, WHETHER IN AN ACTION OF CONTRACT, TORT OR OTHERWISE, ARISING FROM,
 * OUT OF OR IN CONNECTION WITH THE SOFTWARE OR THE USE OR OTHER DEALINGS IN
 * THE SOFTWARE.
 */

/**
 * @file AudioControlSGTL5000Vindor.cpp
 * @author Fernando Trias
 * @brief 
 * @version 0.1
 * @date 2021-02-26
 * 
 * @copyright Modifications Copyright (c) 2013-2021 by Vindor Music, Inc.
 * 
 */

#include "control_sgtl5000.h"
#include "MyWire.h"

#include "AudioControlSGTL5000Vindor.h"

#define CHIP_ID				0x0000
// 15:8 PARTID		0xA0 - 8 bit identifier for SGTL5000
// 7:0  REVID		0x00 - revision number for SGTL5000.

#define CHIP_DIG_POWER			0x0002
// 6	ADC_POWERUP	1=Enable, 0=disable the ADC block, both digital & analog, 
// 5	DAC_POWERUP	1=Enable, 0=disable the DAC block, both analog and digital
// 4	DAP_POWERUP	1=Enable, 0=disable the DAP block
// 1	I2S_OUT_POWERUP	1=Enable, 0=disable the I2S data output
// 0	I2S_IN_POWERUP	1=Enable, 0=disable the I2S data input

#define CHIP_CLK_CTRL			0x0004
// 5:4	RATE_MODE	Sets the sample rate mode. MCLK_FREQ is still specified
//			relative to the rate in SYS_FS
//				0x0 = SYS_FS specifies the rate
//				0x1 = Rate is 1/2 of the SYS_FS rate
//				0x2 = Rate is 1/4 of the SYS_FS rate
//				0x3 = Rate is 1/6 of the SYS_FS rate
// 3:2	SYS_FS		Sets the internal system sample rate (default=2)
//				0x0 = 32 kHz
//				0x1 = 44.1 kHz
//				0x2 = 48 kHz
//				0x3 = 96 kHz
// 1:0	MCLK_FREQ	Identifies incoming SYS_MCLK frequency and if the PLL should be used
//				0x0 = 256*Fs
//				0x1 = 384*Fs
//				0x2 = 512*Fs
//				0x3 = Use PLL
//				The 0x3 (Use PLL) setting must be used if the SYS_MCLK is not
//				a standard multiple of Fs (256, 384, or 512). This setting can
//				also be used if SYS_MCLK is a standard multiple of Fs.
//				Before this field is set to 0x3 (Use PLL), the PLL must be
//				powered up by setting CHIP_ANA_POWER->PLL_POWERUP and
//				CHIP_ANA_POWER->VCOAMP_POWERUP.  Also, the PLL dividers must
//				be calculated based on the external MCLK rate and
//				CHIP_PLL_CTRL register must be set (see CHIP_PLL_CTRL register
//				description details on how to calculate the divisors).

#define CHIP_I2S_CTRL			0x0006
// 8	SCLKFREQ	Sets frequency of I2S_SCLK when in master mode (MS=1). When in slave
//			mode (MS=0), this field must be set appropriately to match SCLK input
//			rate.
//				0x0 = 64Fs
//				0x1 = 32Fs - Not supported for RJ mode (I2S_MODE = 1)
// 7	MS		Configures master or slave of I2S_LRCLK and I2S_SCLK.
//				0x0 = Slave: I2S_LRCLK an I2S_SCLK are inputs
//				0x1 = Master: I2S_LRCLK and I2S_SCLK are outputs
//				NOTE: If the PLL is used (CHIP_CLK_CTRL->MCLK_FREQ==0x3),
//				the SGTL5000 must be a master of the I2S port (MS==1)
// 6	SCLK_INV	Sets the edge that data (input and output) is clocked in on for I2S_SCLK
//				0x0 = data is valid on rising edge of I2S_SCLK
//				0x1 = data is valid on falling edge of I2S_SCLK
// 5:4	DLEN		I2S data length (default=1)
//				0x0 = 32 bits (only valid when SCLKFREQ=0),
//					not valid for Right Justified Mode
//				0x1 = 24 bits (only valid when SCLKFREQ=0)
//				0x2 = 20 bits
//				0x3 = 16 bits
// 3:2	I2S_MODE	Sets the mode for the I2S port
//				0x0 = I2S mode or Left Justified (Use LRALIGN to select)
//				0x1 = Right Justified Mode
//				0x2 = PCM Format A/B
//				0x3 = RESERVED
// 1	LRALIGN		I2S_LRCLK Alignment to data word. Not used for Right Justified mode
//				0x0 = Data word starts 1 I2S_SCLK delay after I2S_LRCLK
//					transition (I2S format, PCM format A)
//				0x1 = Data word starts after I2S_LRCLK transition (left
//					justified format, PCM format B)
// 0	LRPOL		I2S_LRCLK Polarity when data is presented.
//				0x0 = I2S_LRCLK = 0 - Left, 1 - Right
//				1x0 = I2S_LRCLK = 0 - Right, 1 - Left
//				The left subframe should be presented first regardless of
//				the setting of LRPOL.

#define CHIP_SSS_CTRL			0x000A
// 14	DAP_MIX_LRSWAP	DAP Mixer Input Swap
//				0x0 = Normal Operation
//				0x1 = Left and Right channels for the DAP MIXER Input are swapped.
// 13	DAP_LRSWAP	DAP Mixer Input Swap
//				0x0 = Normal Operation
//				0x1 = Left and Right channels for the DAP Input are swapped
// 12	DAC_LRSWAP	DAC Input Swap
//				0x0 = Normal Operation
//				0x1 = Left and Right channels for the DAC are swapped
// 10	I2S_LRSWAP	I2S_DOUT Swap
//				0x0 = Normal Operation
//				0x1 = Left and Right channels for the I2S_DOUT are swapped
// 9:8	DAP_MIX_SELECT	Select data source for DAP mixer
//				0x0 = ADC
//				0x1 = I2S_IN
//				0x2 = Reserved
//				0x3 = Reserved
// 7:6	DAP_SELECT	Select data source for DAP
//				0x0 = ADC
//				0x1 = I2S_IN
//				0x2 = Reserved
//				0x3 = Reserved
// 5:4	DAC_SELECT	Select data source for DAC (default=1)
//				0x0 = ADC
//				0x1 = I2S_IN
//				0x2 = Reserved
//				0x3 = DAP
// 1:0	I2S_SELECT	Select data source for I2S_DOUT
//				0x0 = ADC
//				0x1 = I2S_IN
//				0x2 = Reserved
//				0x3 = DAP
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

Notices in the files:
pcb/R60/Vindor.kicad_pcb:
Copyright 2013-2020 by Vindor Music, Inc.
